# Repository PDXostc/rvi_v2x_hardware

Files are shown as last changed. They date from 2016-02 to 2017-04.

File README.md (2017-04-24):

# rvi_v2x_hardware

This repo contains the Hardware design files for the JLR OSTC V2X project. 

Firmware for an open source CAN/OBD2/2G/3G/GPS/Accelerometer with Power sequencing of RaspberryPi 2B host with RVI node installed.

Tools in use:
- Microsoft Visio - high level archetecture diagrams
- Microsoft Excel - Bill Of Materials 
- Kicad - Electrical Schematic, PCB Layout, 3D rendering, Gerber Viewer (output), Integrated BOM information. Available at http://kicad-pcb.org/
- LTspice IV - SPICE simulator, schematic capture and waveform viewer. Available at http://www.linear.com/designtools/software/
- FOXIT - PDF printer and viewer. Available at https://www.foxitsoftware.com/products/pdf-reader/

Coresponding git repositories

- Spread sheet for organizing data exported from KICad Bom wizard: https://github.com/jbanks2/KiCad-BOM-export-tool.git
- Kicad Custom Part Libraries for V2X project: https://github.com/jbanks2/Kicad_Custom_Parts.git

Primary Development by Jesse Banks - jesse@jopeldesigns.com

Jaguar Land Rover OSTC - Portland, Oregon 2015-2016

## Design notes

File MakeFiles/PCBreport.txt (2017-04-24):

Info: Reading netlist file "C:\Users\Jesse\Documents\JopelDesigns\Projects\rvi_v2x_hardware\MakeFiles\V2X.net".

Info: Using references to match components and footprints.

* Warning: component 'C51': board footprint 'CustomParts:C_0603_SM', netlist footprint 'CustomParts:C_0805_SM'

* Warning: component 'X1': board footprint 'CustomParts:AWSCR', netlist footprint 'Custom:AWSCR'

* Warning: component 'X2': board footprint 'CustomParts:AWSCR', netlist footprint 'Custom:AWSCR'

Error: No footprint defined for component 'P2'.

Error: No footprint defined for component 'W1'.

Info: Checking netlist component footprint "C1:/55AB3ADF/56065471:CustomParts:C_0603_SM".

Info: Checking netlist component footprint "C2:/55AB3ADF/56046502:CustomParts:C_0603_SM".

Info: Checking netlist component footprint "C3:/55AB3ADF/55B1F376:CustomParts:C_0603_SM".

Info: Checking netlist component footprint "C4:/55AB3ADF/5606AD61:CustomParts:C_0603_SM".

Info: Checking netlist component footprint "C5:/55AB3ADF/56048D13:CustomParts:C_0603_SM".

Info: Checking netlist component footprint "C6:/55AB3ADF/5604E07D:CustomParts:C_0603_SM".

Info: Checking netlist component footprint "C7:/55AB3ADF/5604EB81:CustomParts:C_0603_SM".

Info: Checking netlist component footprint "C8:/55AB3ADF/56049282:CustomParts:C_0805_SM".

Info: Checking netlist component footprint "C9:/55AB3ADF/5604DEF3:CustomParts:C_0603_SM".

Info: Checking netlist component footprint "C10:/55AB3ADF/5604F281:CustomParts:C_0603_SM".

Info: Checking netlist component footprint "C11:/55AB3ADF/5604F3BB:CustomParts:C_0603_SM".

Info: Checking netlist component footprint "C12:/55AB3ADF/5604ECAE:CustomParts:C_0603_SM".

Info: Checking netlist component footprint "C13:/55AB3850/55AA984D:CustomParts:C_0603_SM".

Info: Checking netlist component footprint "C14:/55AB3850/567B0C07:Capacitors_SMD:c_elec_6.3x5.8".

Info: Checking netlist component footprint "C15:/55AB3850/55FBBA04:CustomParts:C_0603_SM".

Info: Checking netlist component footprint "C16:/55AB3850/567B0BF4:CustomParts:C_0805_SM".

Info: Checking netlist component footprint "C17:/55AB3850/56290CF9:CustomParts:C_0603_SM".

Changing component "C17:/55AB3850/56290CF9" pin "1" net name from "GND" to "BUTTON".

Changing component "C17:/55AB3850/56290CF9" pin "2" net name from "BUTTON" to "GND".

Info: Checking netlist component footprint "C18:/55AB3850/567B0C17:CustomParts:C_0603_SM".

Info: Checking netlist component footprint "C19:/55AB3850/55AAA21C:Capacitors_SMD:c_elec_6.3x5.8".

Info: Checking netlist component footprint "C20:/55AB3850/560779B3:CustomParts:C_1206_SM".

Info: Checking netlist component footprint "C21:/55AB3850/567B0C2F:Capacitors_SMD:c_elec_6.3x5.8".

Info: Checking netlist component footprint "C22:/55AB3850/567B0BDB:CustomParts:C_0603_SM".

Info: Checking netlist component footprint "C23:/55AB3850/567B0C27:CustomParts:C_0805_SM".

Info: Checking netlist component footprint "C24:/55AB3850/55FBBA48:CustomParts:C_1206_SM".

Info: Checking netlist component footprint "C25:/55AB3850/567B8999:CustomParts:C_0603_SM".

Info: Checking netlist component footprint "C26:/55AB3850/567B0C3F:CustomParts:C_0603_SM".

Info: Checking netlist component footprint "C27:/55AB3850/567B8991:CustomParts:C_0805_SM".

Info: Checking netlist component footprint "C28:/55AB3850/567B0C95:CustomParts:C_1206_SM".

Info: Checking netlist component footprint "C29:/55AB3850/567B15E2:CustomParts:C_0603_SM".

Info: Checking netlist component footprint "C30:/55AB3850/567B0C9D:CustomParts:C_1206_SM".

Info: Checking netlist component footprint "C31:/55AB3850/567B0CA5:CustomParts:C_1206_SM".

Info: Checking netlist component footprint "C32:/55AB3850/567B237E:CustomParts:C_0603_SM".

Info: Checking netlist component footprint "C33:/55F8B2F2/56053914:CustomParts:C_0603_SM".

Info: Checking netlist component footprint "C34:/55F8B2F2/55F8B394:CustomParts:C_0603_SM".

Info: Checking netlist component footprint "C35:/55F8B2F2/56053A8A:CustomParts:C_0603_SM".

Info: Checking netlist component footprint "C36:/55F8B2F2/567BDBCA:CustomParts:C_0603_SM".

Info: Checking netlist component footprint "C37:/55F8B2F2/567BDBA4:CustomParts:C_0805_SM".

Info: Checking netlist component footprint "C38:/55F8B2F2/56053852:CustomParts:C_0603_SM".

Info: Checking netlist component footprint "C39:/55AB3850/569FD08D:CustomParts:C_0603_SM".

Info: Checking netlist component footprint "C40:/55AB3850/569FD0B0:CustomParts:C_0603_SM".

Info: Checking netlist component footprint "C41:/55F91B74/56052557:CustomParts:C_0603_SM".

Info: Checking netlist component footprint "C42:/55F91B74/56052E12:CustomParts:C_0603_SM".

Info: Checking netlist component footprint "C43:/55F91B74/56052E7D:CustomParts:C_0603_SM".

Info: Checking netlist component footprint "C44:/55F91B74/56052EE9:CustomParts:C_0603_SM".

Info: Checking netlist component footprint "C45:/55F91B74/56052F58:CustomParts:C_0603_SM".

Info: Checking netlist component footprint "C46:/55F91B74/56059C07:CustomParts:C_0603_SM".

Info: Checking netlist component footprint "C47:/562004BB/55A9296E:Capacitors_ThroughHole:C_Radial_D12.5_L25_P5".

Info: Checking netlist component footprint "C48:/562004BB/55A9A6E2:CustomParts:C_0603_SM".

Info: Checking netlist component footprint "C49:/562004BB/5603FFF9:CustomParts:C_0603_SM".

Info: Checking netlist component footprint "C50:/562004BB/5603E72B:CustomParts:C_0603_SM".

Info: Checking netlist component footprint "C51:/562004BB/560FE5DA:CustomParts:C_0805_SM".

Info: Checking netlist component footprint "C52:/55F91B74/56A157E6:CustomParts:C_0603_SM".

Info: Checking netlist component footprint "C53:/55F91B74/56DA13C3:CustomParts:C_0603_SM".

Info: Checking netlist component footprint "C54:/55F91B74/56DA1977:CustomParts:C_0603_SM".

Info: Checking netlist component footprint "C55:/55AB3850/58E1BBA0:CustomParts:C_1206_SM".

Adding new component "C55:/55AB3850/58E1BBA0" footprint "CustomParts:C_1206_SM".

Info: Checking netlist component footprint "D1:/55AB3ADF/5605B7C0:CustomParts:Diode_0805_12_SM".

Info: Checking netlist component footprint "D2:/55AB3ADF/55B40CD4:CustomParts:Diode_0805_12_SM".

Info: Checking netlist component footprint "D3:/55AB3ADF/56046C18:CustomParts:Diode_0805_12_SM".

Info: Checking netlist component footprint "D4:/55AB3ADF/5605B14B:CustomParts:Diode_0805_12_SM".

Info: Checking netlist component footprint "D5:/55AB3ADF/5605AAE2:CustomParts:Diode_0805_12_SM".

Info: Checking netlist component footprint "D6:/55AB3850/55AAA079:Diodes_SMD:SMB_Standard".

Info: Checking netlist component footprint "D7:/55AB3850/55AAA128:Diodes_SMD:SMA_Standard".

Info: Checking netlist component footprint "D8:/55AB3850/5607A783:CustomParts:SOD-123".

Info: Checking netlist component footprint "D9:/55AB3850/56454B6A:CustomParts:Diode_0805_12_SM".

Info: Checking netlist component footprint "D10:/55AB3850/567B0C5F:CustomParts:SOD-123".

Info: Checking netlist component footprint "D11:/55F91B74/560D95B2:CustomParts:0805_LED".

Info: Checking netlist component footprint "D12:/55F91B74/55FD725A:CustomParts:0805_LED".

Info: Checking netlist component footprint "D13:/55F91B74/55FD764E:CustomParts:0805_LED".

Info: Checking netlist component footprint "F1:/55AB3850/55A6CDC7:Resistors_SMD:R_1812".

Info: Checking netlist component footprint "F2:/55AB3850/55C7D59B:Resistors_SMD:R_1812".

Info: Checking netlist component footprint "FB1:/55AB3ADF/5604928A:CustomParts:R_0603_sm".

Info: Checking netlist component footprint "FB2:/55AB3850/567B0BD3:CustomParts:R_0603_sm".

Info: Checking netlist component footprint "FB3:/55F8B2F2/567BDBAC:CustomParts:R_0603_sm".

Info: Checking netlist component footprint "FB4:/55F91B74/56059F9F:CustomParts:R_0603_sm".

Info: Checking netlist component footprint "J1:/55AB3ADF/55B3C04C:Custom:DB-9_SMT".

Info: Checking netlist component footprint "L1:/55AB3850/5607B402:CustomParts:L_4.5x4.5".

Info: Checking netlist component footprint "L2:/55AB3850/567B0CB5:CustomParts:L_4.5x4.5".

Info: Checking netlist component footprint "L3:/562004BB/5603E335:CustomParts:L_0603_SM".

Info: Checking netlist component footprint "L4:/562004BB/55A9A7AD:CustomParts:L_0603_SM".

Info: Checking netlist component footprint "P1:/55AB3ADF/55AA08F9:CustomParts:R_0603_sm".

Info: Checking netlist component footprint "P2:/55AB3ADF/55B92A71:".

Error: Cannot add new component "P2:/55AB3ADF/55B92A71" due to missing footprint "".

Info: Checking netlist component footprint "P3:/55AB3850/561FEF14:CustomParts:USB-A-SMT".

Info: Checking netlist component footprint "P4:/55AB3850/55C35935:Mounting_Holes:MountingHole_3mm".

Info: Checking netlist component footprint "P5:/55AB3850/55C3593C:Mounting_Holes:MountingHole_3mm".

Info: Checking netlist component footprint "P6:/55AB3850/55C35943:Mounting_Holes:MountingHole_3mm".

Info: Checking netlist component footprint "P7:/55AB3850/55C3594A:Mounting_Holes:MountingHole_3mm".

Info: Checking netlist component footprint "P8:/55AB3850/55C35919:Fiducials:Fiducial_1mm_Dia_2.54mm_Outer_CopperTop".

Info: Checking netlist component footprint "P9:/55AB3850/55C35920:Fiducials:Fiducial_1mm_Dia_2.54mm_Outer_CopperTop".

Info: Checking netlist component footprint "P10:/55AB3850/55C35927:Fiducials:Fiducial_1mm_Dia_2.54mm_Outer_CopperTop".

Info: Checking netlist component footprint "P11:/55AB3850/55C3592E:Fiducials:Fiducial_1mm_Dia_2.54mm_Outer_CopperTop".

Info: Checking netlist component footprint "P12:/55AB3850/562955D0:Fiducials:Fiducial_1mm_Dia_2.54mm_Outer_CopperBottom".

Info: Checking netlist component footprint "P13:/55AB3850/562955D6:Fiducials:Fiducial_1mm_Dia_2.54mm_Outer_CopperBottom".

Info: Checking netlist component footprint "P14:/55AB3850/562955DC:Fiducials:Fiducial_1mm_Dia_2.54mm_Outer_CopperBottom".

Info: Checking netlist component footprint "P15:/55AB3850/562955E2:Fiducials:Fiducial_1mm_Dia_2.54mm_Outer_CopperBottom".

Info: Checking netlist component footprint "P16:/55F8B2F2/567BADA8:CustomParts:USB_Micro-B-DX4R005JJ2R1800".

Info: Checking netlist component footprint "P22:/562004BB/5603F238:CustomParts:SMA-RA_142-0701-801".

Info: Checking netlist component footprint "P23:/562004BB/55A9FAEF:CustomParts:SMA-RA_142-0701-801".

Info: Checking netlist component footprint "P24:/562004BB/55A754E2:CustomParts:47553-1001".

Info: Checking netlist component footprint "PDI1:/55F91B74/55F86EF7:Pin_Headers:Pin_Header_Straight_2x03".

Info: Checking netlist component footprint "Q1:/55AB3ADF/5605E65B:CustomParts:SOT_23_123".

Info: Checking netlist component footprint "Q2:/55AB3ADF/5605E101:CustomParts:SOT_23_123".

Info: Checking netlist component footprint "Q3:/55AB3ADF/5605DFA8:CustomParts:SOT_23_123".

Info: Checking netlist component footprint "Q4:/55AB3ADF/560643DB:CustomParts:SOT_23_123".

Info: Checking netlist component footprint "Q5:/55AB3ADF/55B35B80:CustomParts:SOT_23_123".

Info: Checking netlist component footprint "Q6:/55AB3ADF/55B35FD6:CustomParts:SOT_23_123".

Info: Checking netlist component footprint "Q7:/55AB3ADF/560521FD:CustomParts:SOT_23_123".

Info: Checking netlist component footprint "Q8:/55AB3ADF/560520AD:CustomParts:SOT_23_123".

Info: Checking netlist component footprint "Q9:/55AB3ADF/56052C71:CustomParts:SOT_23_123".

Info: Checking netlist component footprint "Q10:/55AB3ADF/55B7C06D:CustomParts:SOT_23_123".

Info: Checking netlist component footprint "Q11:/55AB3850/5607ABF7:CustomParts:SOIC-8_MOS".

Info: Checking netlist component footprint "Q12:/55AB3850/567B0CAD:CustomParts:SOIC-8_MOS".

Info: Checking netlist component footprint "Q15:/55F91B74/55FE0BA7:CustomParts:SOT_23_123".

Info: Checking netlist component footprint "R1:/55AB3ADF/55B20162:CustomParts:R_1210_SM".

Info: Checking netlist component footprint "R2:/55AB3ADF/56062E2E:CustomParts:R_1210_SM".

Info: Checking netlist component footprint "R3:/55AB3ADF/56068A93:CustomParts:R_0603_sm".

Info: Checking netlist component footprint "R4:/55AB3ADF/55B2AB74:CustomParts:R_0603_sm".

Info: Checking netlist component footprint "R5:/55AB3ADF/560629BB:CustomParts:R_0603_sm".

Info: Checking netlist component footprint "R6:/55AB3ADF/56062B17:CustomParts:R_0603_sm".

Info: Checking netlist component footprint "R7:/55AB3ADF/5605C4B6:CustomParts:R_0603_sm".

Info: Checking netlist component footprint "R8:/55AB3ADF/5605C5FE:CustomParts:R_0603_sm".

Info: Checking netlist component footprint "R9:/55AB3ADF/5605C791:CustomParts:R_0603_sm".

Info: Checking netlist component footprint "R10:/55AB3ADF/56060ABE:CustomParts:R_0603_sm".

Info: Checking netlist component footprint "R11:/55AB3ADF/56061D1B:CustomParts:R_0603_sm".

Info: Checking netlist component footprint "R12:/55AB3ADF/5605C36B:CustomParts:R_0603_sm".

Info: Checking netlist component footprint "R13:/55AB3ADF/5605DA36:CustomParts:R_0603_sm".

Info: Checking netlist component footprint "R14:/55AB3ADF/5605C1F3:CustomParts:R_0603_sm".

Info: Checking netlist component footprint "R15:/55AB3ADF/5605DB8E:CustomParts:R_0603_sm".

Info: Checking netlist component footprint "R16:/55AB3ADF/5605D779:CustomParts:R_0603_sm".

Info: Checking netlist component footprint "R17:/55AB3ADF/5605D8F7:CustomParts:R_0603_sm".

Info: Checking netlist component footprint "R18:/55AB3ADF/5605BA35:CustomParts:R_0603_sm".

Info: Checking netlist component footprint "R19:/55AB3ADF/55B355D8:CustomParts:R_0603_sm".

Info: Checking netlist component footprint "R20:/55AB3ADF/55B35518:CustomParts:R_0603_sm".

Info: Checking netlist component footprint "R21:/55AB3ADF/5605BC94:CustomParts:R_0603_sm".

Info: Checking netlist component footprint "R22:/55AB3ADF/55B1F414:CustomParts:R_0603_sm".

Info: Checking netlist component footprint "R23:/55AB3ADF/5605BE37:CustomParts:R_0603_sm".

Info: Checking netlist component footprint "R24:/55AB3ADF/55BD0AC0:CustomParts:R_0603_sm".

Info: Checking netlist component footprint "R25:/55AB3ADF/55BD137A:CustomParts:R_0603_sm".

Info: Checking netlist component footprint "R26:/55AB3ADF/5606AA56:CustomParts:R_0603_sm".

Info: Checking netlist component footprint "R27:/55AB3ADF/55B34CA2:CustomParts:R_0603_sm".

Info: Checking netlist component footprint "R28:/55AB3ADF/5605B2E0:CustomParts:R_0603_sm".

Info: Checking netlist component footprint "R29:/55AB3ADF/5606B363:CustomParts:R_0603_sm".

Info: Checking netlist component footprint "R30:/55AB3ADF/560537AD:CustomParts:R_0603_sm".

Info: Checking netlist component footprint "R31:/55AB3ADF/5605393B:CustomParts:R_0603_sm".

Info: Checking netlist component footprint "R32:/55AB3ADF/55AA1169:CustomParts:R_0603_sm".

Info: Checking netlist component footprint "R33:/55AB3ADF/5655F6EA:CustomParts:R_0603_sm".

Info: Checking netlist component footprint "R34:/55AB3ADF/56058495:CustomParts:R_0603_sm".

Info: Checking netlist component footprint "R35:/55AB3ADF/5605879F:CustomParts:R_0603_sm".

Info: Checking netlist component footprint "R36:/55AB3ADF/56059C7F:CustomParts:R_0603_sm".

Info: Checking netlist component footprint "R37:/55AB3850/56081053:CustomParts:R_0603_sm".

Info: Checking netlist component footprint "R38:/55AB3850/5608243D:CustomParts:R_0603_sm".

Info: Checking netlist component footprint "R39:/55AB3850/5608085B:CustomParts:R_0603_sm".

Info: Checking netlist component footprint "R40:/55AB3850/5608BED0:CustomParts:R_0603_sm".

Info: Checking netlist component footprint "R41:/55AB3850/56081C97:CustomParts:R_0603_sm".

Info: Checking netlist component footprint "R42:/55AB3850/560811F0:CustomParts:R_0603_sm".

Info: Checking netlist component footprint "R43:/55AB3850/56081A63:CustomParts:R_0603_sm".

Info: Checking netlist component footprint "R44:/55AB3850/56081EB1:CustomParts:R_0603_sm".

Info: Checking netlist component footprint "R45:/55AB3850/567B0CC5:CustomParts:R_0603_sm".

Info: Checking netlist component footprint "R46:/55AB3850/5644A6DA:CustomParts:R_0603_sm".

Info: Checking netlist component footprint "R47:/55AB3850/567B0CCD:CustomParts:R_0603_sm".

Info: Checking netlist component footprint "R51:/55AB3850/5627A597:CustomParts:R_0603_sm".

Info: Checking netlist component footprint "R52:/55AB3850/5627A58F:CustomParts:R_0603_sm".

Info: Checking netlist component footprint "R53:/55F8B2F2/5627871B:CustomParts:R_0603_sm".

Info: Checking netlist component footprint "R54:/55F8B2F2/56278723:CustomParts:R_0603_sm".

Info: Checking netlist component footprint "R55:/55F8B2F2/55F89B1E:CustomParts:R_0603_sm".

Info: Checking netlist component footprint "R56:/55F8B2F2/567BBCB0:CustomParts:R_0603_sm".

Info: Checking netlist component footprint "R57:/55F8B2F2/5627F762:CustomParts:R_0603_sm".

Info: Checking netlist component footprint "R58:/55F8B2F2/5627F427:CustomParts:R_0603_sm".

Info: Checking netlist component footprint "R59:/55F8B2F2/567BBCEF:CustomParts:R_0603_sm".

Info: Checking netlist component footprint "R61:/55F91B74/560D95D8:CustomParts:R_0603_sm".

Info: Checking netlist component footprint "R63:/55F91B74/5605C9A1:CustomParts:R_0603_sm".

Info: Checking netlist component footprint "R66:/55F91B74/562AAD52:CustomParts:R_0603_sm".

Info: Checking netlist component footprint "R67:/55F91B74/5605AFDD:CustomParts:R_0603_sm".

Info: Checking netlist component footprint "R69:/562004BB/5603C783:CustomParts:R_0603_sm".

Info: Checking netlist component footprint "R70:/562004BB/55A77FC7:CustomParts:R_0603_sm".

Info: Checking netlist component footprint "R71:/562004BB/5603C7FB:CustomParts:R_0603_sm".

Info: Checking netlist component footprint "SW1:/55AB3ADF/55F7E47B:CustomParts:SW_SPST_FSMSM_SM".

Info: Checking netlist component footprint "SW2:/55AB3850/5600CE81:CustomParts:PTS645VK58-2-LFS".

Info: Checking netlist component footprint "U1:/55AB3ADF/55B2A9F7:Housings_SOIC:SOIC-14_3.9x8.7mm_Pitch1.27mm".

Info: Checking netlist component footprint "U2:/55AB3ADF/55C1089B:TO_SOT_Packages_SMD:SOT-23-6".

Info: Checking netlist component footprint "U3:/55AB3ADF/5604541F:TO_SOT_Packages_SMD:SOT-23-6".

Info: Checking netlist component footprint "U4:/55AB3ADF/55B33F41:TO_SOT_Packages_SMD:SOT-223".

Info: Checking netlist component footprint "U5:/55AB3ADF/55B1E71A:Housings_SOIC:SOIC-8_3.9x4.9mm_Pitch1.27mm".

Info: Checking netlist component footprint "U6:/55AB3ADF/55A9EA92:Housings_SOIC:SOIC-28_7.5x17.9mm_Pitch1.27mm".

Info: Checking netlist component footprint "U7:/55AB3850/5643FA88:TO_SOT_Packages_SMD:SOT-23-6".

Info: Checking netlist component footprint "U8:/55AB3850/5607E4F1:TO_SOT_Packages_SMD:SOT-23-5".

Info: Checking netlist component footprint "U9:/55AB3850/567B0CBD:TO_SOT_Packages_SMD:SOT-23-5".

Info: Checking netlist component footprint "U10:/55AB3850/56A695E2:TO_SOT_Packages_SMD:SOT-23-6".

Info: Checking netlist component footprint "U11:/55AB3850/567B8989:TO_SOT_Packages_SMD:SOT-23-5".

Info: Checking netlist component footprint "U12:/55AB3850/567B15D2:TO_SOT_Packages_SMD:SOT-23-5".

Info: Checking netlist component footprint "U13:/55AB3850/569FD086:TO_SOT_Packages_SMD:SOT-23-5".

Info: Checking netlist component footprint "U16:/55F8B2F2/55F88FA9:Housings_DFN_QFN:QFN-24-1EP_4x4mm_Pitch0.5mm".

Info: Checking netlist component footprint "U17:/55F8B2F2/567BDB8D:CustomParts:LGA-14_5x3mm".

Info: Checking netlist component footprint "U18:/55F91B74/55FA3B36:Housings_SOIC:SOIC-16_3.9x9.9mm_Pitch1.27mm".

Info: Checking netlist component footprint "U20:/55F91B74/55F86EE3:Housings_QFP:TQFP-44_10x10mm_Pitch0.8mm".

Info: Checking netlist component footprint "U22:/562004BB/55A744B0:CustomParts:SIM5320".

Info: Checking netlist component footprint "U23:/562004BB/56099894:TO_SOT_Packages_SMD:SOT-23-6".

Info: Checking netlist component footprint "W1:/562004BB/55B87E9D:".

Error: Cannot add new component "W1:/562004BB/55B87E9D" due to missing footprint "".

Info: Checking netlist component footprint "X1:/55AB3ADF/55B75E65:Custom:AWSCR".

Info: Checking netlist component footprint "X2:/55F8B2F2/56092E15:Custom:AWSCR".

Info: Checking netlist component footprint "X3:/55F91B74/56DA0FEF:Custom Parts:C_1206_SM".

Error: Component 'P8' pad '1' not found in footprint 'Fiducials:Fiducial_1mm_Dia_2.54mm_Outer_CopperTop'

Error: Component 'P9' pad '1' not found in footprint 'Fiducials:Fiducial_1mm_Dia_2.54mm_Outer_CopperTop'

Error: Component 'P10' pad '1' not found in footprint 'Fiducials:Fiducial_1mm_Dia_2.54mm_Outer_CopperTop'

Error: Component 'P11' pad '1' not found in footprint 'Fiducials:Fiducial_1mm_Dia_2.54mm_Outer_CopperTop'

Error: Component 'P12' pad '1' not found in footprint 'Fiducials:Fiducial_1mm_Dia_2.54mm_Outer_CopperBottom'

Error: Component 'P13' pad '1' not found in footprint 'Fiducials:Fiducial_1mm_Dia_2.54mm_Outer_CopperBottom'

Error: Component 'P14' pad '1' not found in footprint 'Fiducials:Fiducial_1mm_Dia_2.54mm_Outer_CopperBottom'

Error: Component 'P15' pad '1' not found in footprint 'Fiducials:Fiducial_1mm_Dia_2.54mm_Outer_CopperBottom'

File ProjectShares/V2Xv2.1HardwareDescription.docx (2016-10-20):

# V2X v2 Hardware Description

Author Jesse Banks

## Architecture

The design of the V2X board has an Atmel microcontroller at its heart. The atmel has 4 primary jobs:

1. control system/sub-system power states and sequencing,
2. creates a control/reporting interface (AT style) for each system,
3. serial adapter/pass through for the ELM327/STN1110 chip,
4. samples and generates a serial stream from accelerometer data.

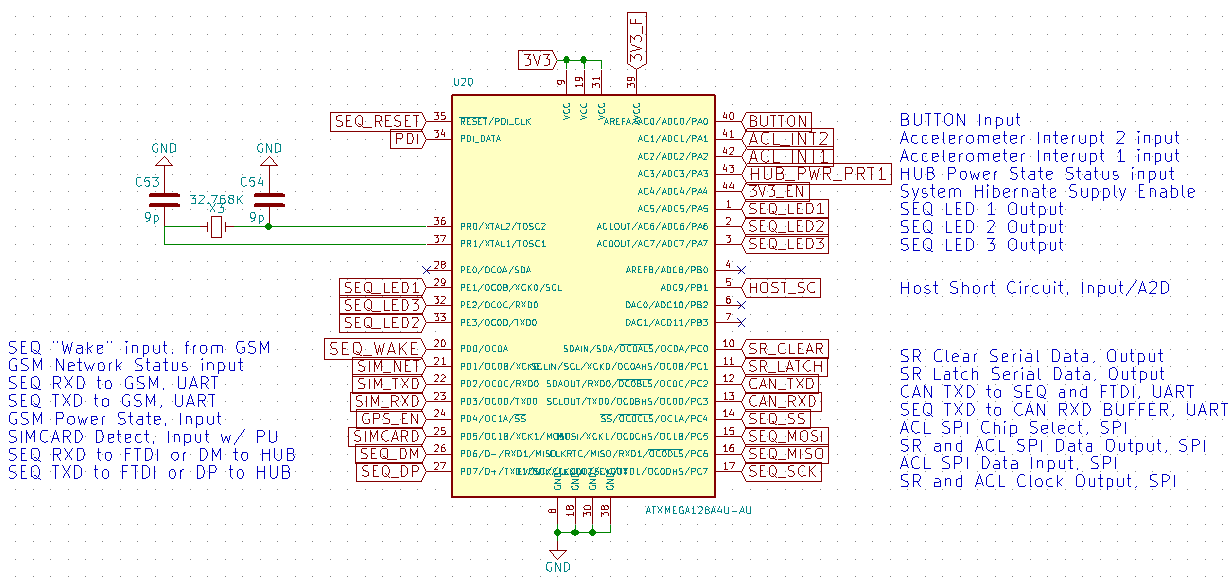
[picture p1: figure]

## Button

When the v2x board first receives power it should remain in an off state. the board has a singular button with dual purposes, starting power and soft button. pressing the button will temporarily enable the 4v1 power supply, passing power through U12 and providing power to the atmel ATmega chip.

The first action of the Atmel needs to be resetting shift registers to the default 0 state, then sending the 4V1_EN or 3V3_EN signal to keep the 3V3 Volt Power System alive. Once the button is released, the 3.3V power supply will shut off if the 4V1_EN or 3V3_EN is not pulled high by the Shift registers.

After starting power, the button it will transition to a soft button function. The BUTTON signal is routed to the ATmega Port A0. It produces a positive logic signal (pin goes high on press). The command interface will report press and release events through the CMD usb port, and will have the following forms:

Press event: Sent to CMD interface: ”BTN:>PRESS\n”

Release event: Sent to CMD interface: ”BTN:>RELEASE:(seconds pressed)\n”

Here is an expeted terminal report:

BTN>:PRESS

BTN>:RELEASE:1

BTN>:PRESS

BTN>:RELEASE:4

## LED

SEQ_LED1, 2, 3 are all negative logic signals, a logic low causes the light to turn on. They can be pulsed at 1-10’s of Khz to create fading using OC0B, OC0C and OC0D (PE1-3).

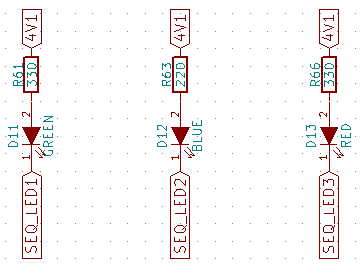
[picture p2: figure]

## Shift registers

The method for controlling power switches and reset signals throughout the board is handled by a 74HC595 serial shift register. the shift register uses the ATmega SPI peripheral bus signals SCK and MOSI, along with dedicated clear and latch signals. Output Enable is signal “G” it is tied to ground so that the outputs are always on, and never high impedance.

The shift register data sheet is here (http://www.mouser.com/ds/2/302/74HC_HCT595_Q100-269352.pdf)

The operational state of SR_CLEAR is ‘1’ (not clear). The shift register reset procedure involves setting SR_CLEAR to ‘0’ (this clears all the shift registers) then cycling SR_LATCH 0->1->0 (moves the clear SR value to the output buffers) and setting SR_CLEAR to ‘1’ again. this operation loads all ‘0’s to the outputs and puts the control signals back in their default states.

SR_CLEAR

SR_LATCH

“1”

“0”

3V3_EN: (not from SR) Low power supply for idle and sleep modes.

4V1_EN: main power supply, needed for GSM and GPS.

5V0_EN Starts switching supply for 5V0 power rail. CAN and HOST

5V0_B_EN: load switch powering HOST

/CAN_SLEEP: suspend signal to CAN device (active low)

/CAN_RESET: reset signal for CAN device (active low)

SIM_PWR_ON: wake-up/shut-down pulse signal

/SIM_RESET: causes the SIM GSM/GPS module to reset

SIM_WAKE: cycles SIM module between sleep and wake states (not implemented yet)

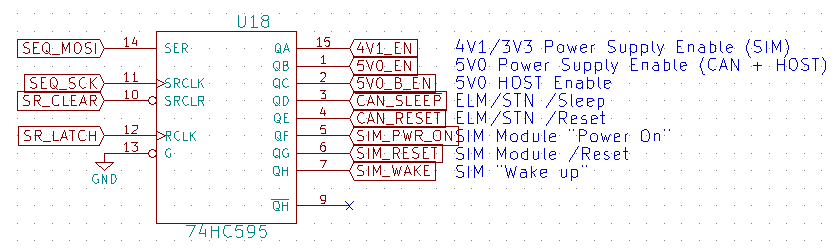
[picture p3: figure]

### 4V1_EN, Main Power

Power switches allow for controlling power to the ATmega, accelerometer, CAN bus controller, GSM/GPS modem, USB hub and FTDI along with the HOST computer itself.

The 3V3 power rail is critical to the ATmega for operation. The 3V3 power can come from 2 sources, but should only be using one at a time (minimize overlap). Identical LDO linear regulators sourcing from 4v1 and filtered 12V are available.

Since linear regulation is wasteful, 4V1 should be used whenever possible. For this reason the enable pin of U12 is tied to 4V1 and will automatically power the 3V3 rail if the 4V1 rail is powered. In this case U13 should be disabled by holding 3V3_EN low. If 4V1 is being powered off for sleep mode then 3V3_EN (port A0) should be set high immediately prior the change, to keep the ATmega alive.

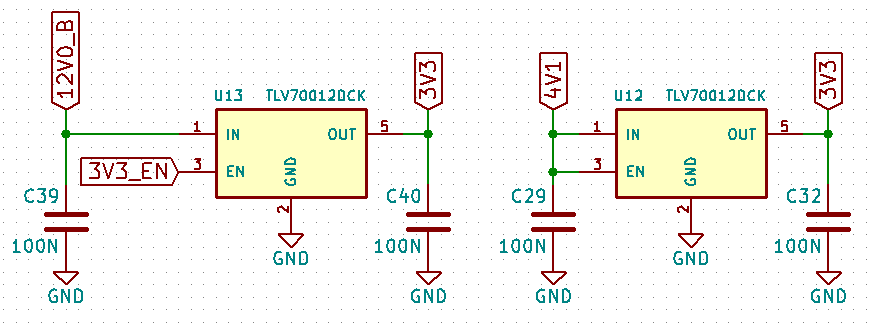
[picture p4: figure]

### 5V0_EN and 5V0_B_EN, CAN and HOST Power

The 5V0_EN signal is set high to start the 5volt power supply, U8. After a short delay (100ms guess) for supply stabilization, the 5V0_B_EN signal is set high to provide the host with power (5V0_B) through power switch U10.

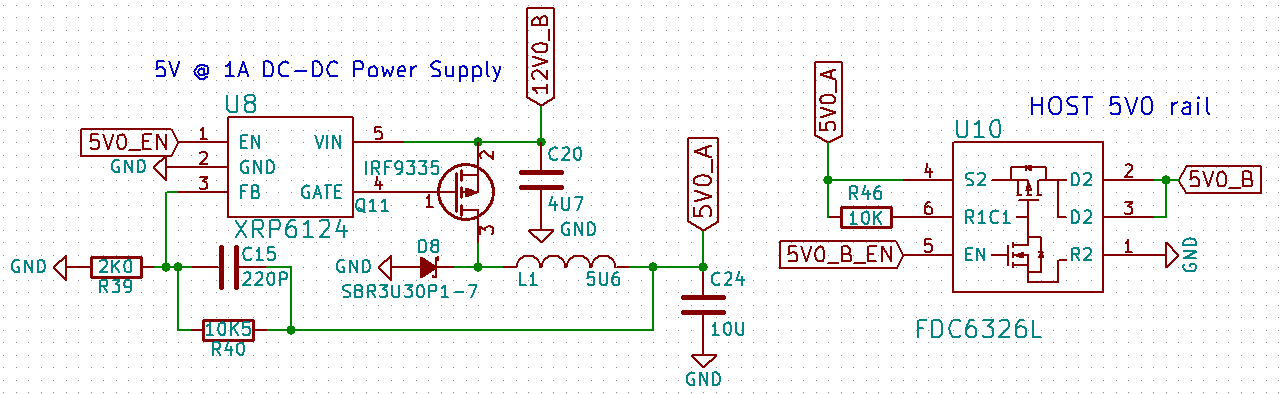
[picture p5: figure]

The HOST would typically be a Raspberry Pi 3, but it could also be a beaglebone, minnowmax, Rpi 1/2, etc. The host receives power from V2X port P3, the USB-A Female port.

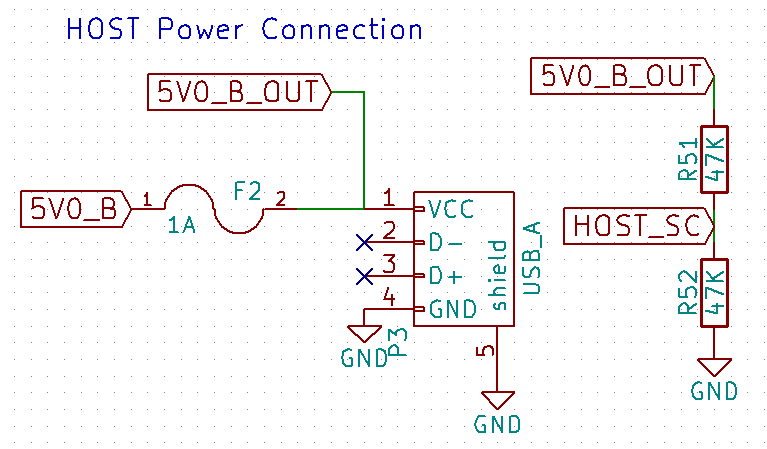
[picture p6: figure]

While 5V0_B_EN is active, HOST_SC could be monitored to determine if there is a short circuit or overload, setting the poly fuse open. if HOST_SC is read as a logic ‘1’ the host is receiving power. A logic ‘0’ indicates the fuse is protecting the power supply. Alternately ADC9 can take an analog sample possibly indicating power usage without overload, nominal values are unknown.

Once the HOST is started the ATmega receives AT-like commands that allows the HOST to modify the power modes and access other features.

### CAN_SLEEP

External sleep control input. When enabled in firmware, puts the device into low - power sleep mode. Polarity of this pin can be configured in firmware; default configuration is active low. Internal pull-up to VDD is enabled by default, but can be disabled in firmware. When STN11xx senses a logic low on the SLEEP pin, it immediately aborts any OBD reception in progress, or monitoring command that is active at the time, and prints the command prompt. It then monitors the SLEEP input and enters the Power Save mode if the minimum low time (specified by the STSLXST command) is satisfied.

### CAN_RESET

Device reset input. A logic low pulse (min 2μs) on this pin will reset the device. Apply a continuous logic low to hold the device in reset.

### SIM_PWR_ON

The SIM5320 module expects a negative pulse to start the module. Here is a quick clip of the SIM module data sheet:

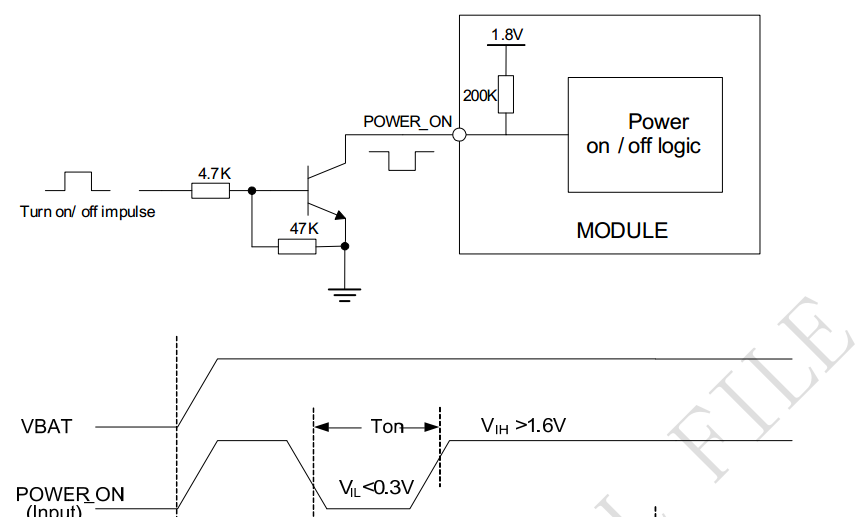
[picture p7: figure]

Q15 transfers a positive pulse from the shift register into the negative signal the SIM is expecting. Also, the Shift register default 0 state should not trigger the SIM module to start falsely. This circuit changes SIM_PWR_ON into SIM_PWR_ON

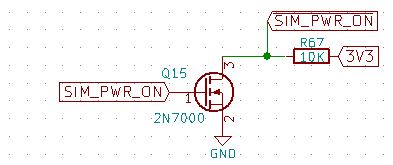
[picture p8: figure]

### SIM_RESET

Should be high to operate the SIM5320 module. Only necessary to use as reset command if SIM stops responding to AT commands.

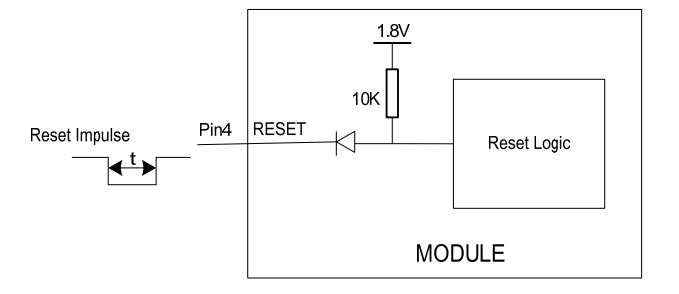
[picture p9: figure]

### SIM_WAKE

The signal wakes the GSM/GPS module from sleep. Not currently implemented, likely requires configuration of SIM module to use.

## Data Paths

HOST Control of the V2X is handled completely over USB. As USB enters the board it lands on a 2 port hub. the hub sends the USB signals to the SIM5320 module and the ATmega.

The SIM produces a 5x USB endpoint interface. they provide the NMEA GPS stream, virtual modem, SMS and GSM control.

The ATmega firmware performs 3 roles (with 3 corresponding USB endpoints): Accelerometer stream, CAN interface serial bypass and system level power sequencing control.

Internal

Internal

Internal

Serial

USB

USB

HOST
USB PORT

2x HUB

ATMEL

USB

CAN

ACL

SIM5320

CMD

Internal

SPI

Serial

GPS

GSM 3G

SMS

## USB Hub

The design uses a USB2422, 2-port automatic hub. Datasheet (http://www.mouser.com/ds/2/268/2422-319423.pdf)

HUB_RESET is automatically pulled low by the chip. It is released by an upstream USB Vdd supply (HOST) connection.

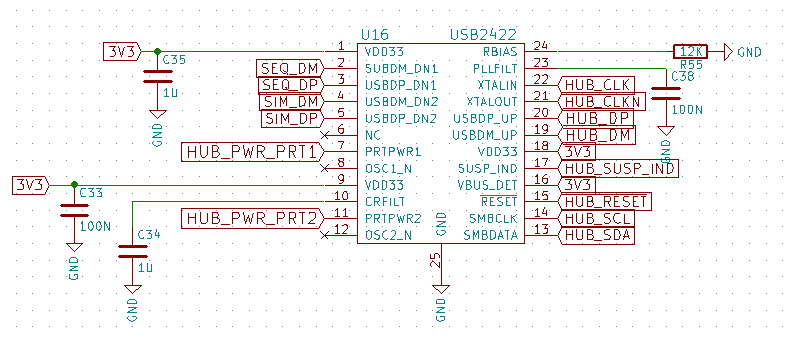
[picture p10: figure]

With the default board configuration the hub should activate and operate automatically as a bus powered 2-port hub. Logic states on several pins are sampled when the 2422 leaves reset (signal goes high) to determine the mode of operation.

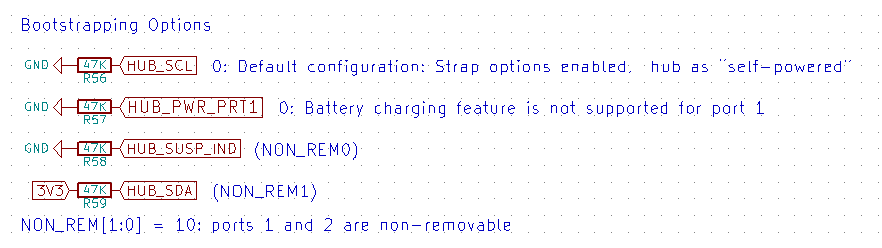
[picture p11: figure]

Non default configurations allow for complete setup and configuration of the hub through SMBUS (I2C) communications. See the datasheet for all the confusion you can handle.

## Serial Data

The ATmega is serially connected to the SIM5320 module and the STN1110. This system has multiple options for configuration.

The driver in the ATmega understands when the USB passthrough channel is open to the HOST. While the HOST is offline (and special modes) the Atmel can directly access the CAN device to search for ignition evidence.

## SIM5320

The GPS System is backed up by a super capacitor for rapid satellite acquisition. First acquisition can take 30+ seconds or more, subsequent acquisitions should be <1 second. The super capacitor should keep the GPS clock running for 36+ hours based on limited info.

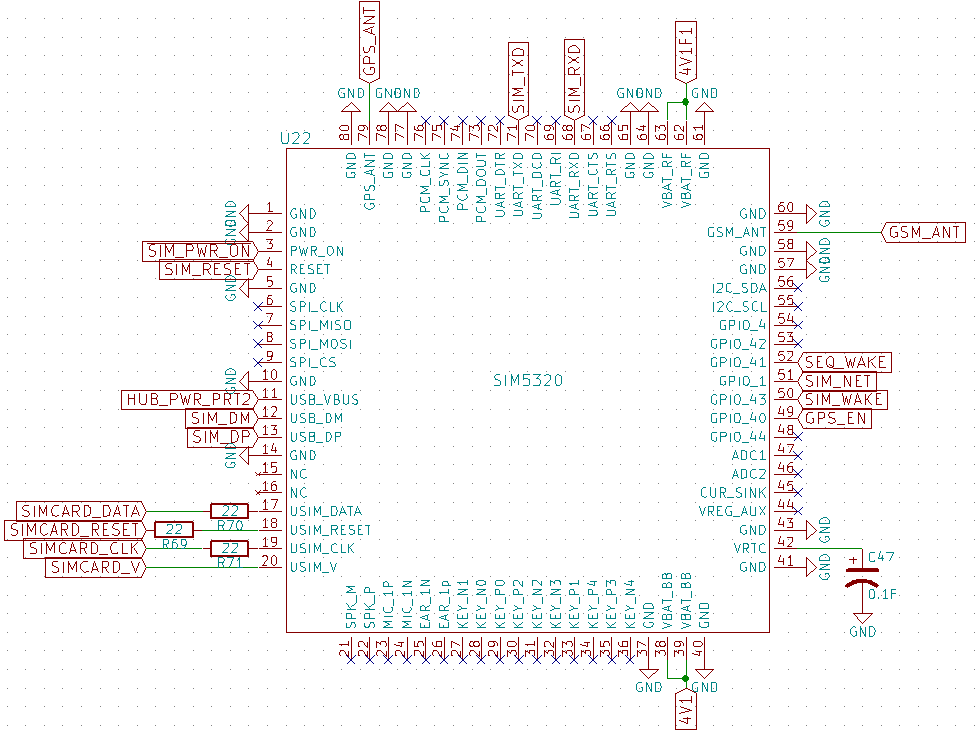
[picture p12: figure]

The primary means of controlling the SIM5320 is by USB connection (SIM_DM, SIM_DP). All functions are mirrored onto a single serial channel with functional multiplexing. The serial method is far more complicated, but gives access to the ATmega while the host is off. Excerpt from the data sheet.

USB mounting is automatically triggered by HUB_PWR_PRT2 signal, generated when the hub successfully mounts to the HOST. USB_VBUS is low otherwise and the USB port is deactivated.

The SIM5320 gets GSM subscription information from a sim card just like any other cell phone. Sim card Card Logic voltage detection and operation is handled automatically.

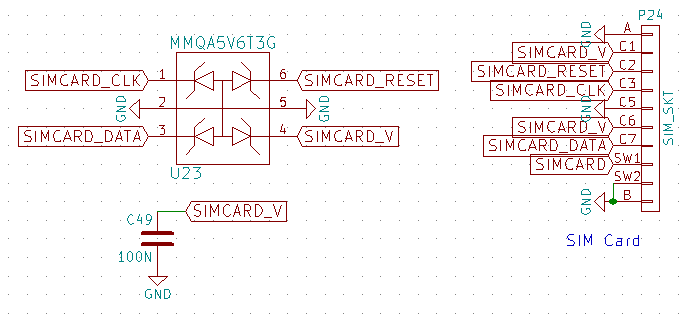
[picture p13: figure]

The sim card socket has a switch (SW1<->SW2) that will close (short) when the card is inserted. PD5 must be configured with a pullup resistor to detect the closed switch to ground. Therefore; SIMCARD, signalling PD5, uses negative logic. When the pin is high there is no sim card in the socket. For highest power efficiency the port-pullup should only be enabled several microseconds before a reading is taken, and disabled immediately afterward, else idle currents will continue to flow.

The SIM connections at the ATmega:

The GPIO connections at the SIM module are:

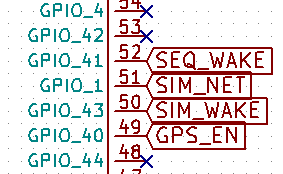
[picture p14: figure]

GPIO functions from the data sheet

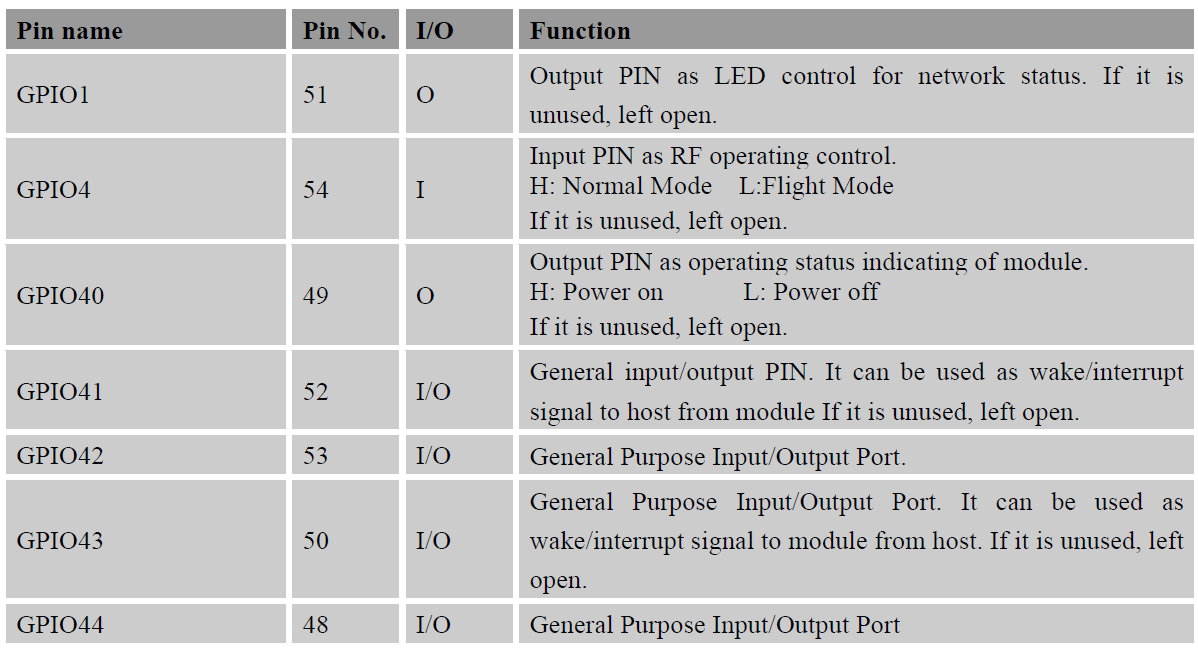
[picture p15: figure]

### GPS_EN

The SIM5320 module is default configured to indicate its power state from GPIO40 (as seen above). The GPS_EN signal sent by this pin serves two purposes; it allows the ATmega to directly sample the power state of the SIM, and it enables the active antenna power supply, necessary for the GPS antenna to operate.

## Accelerometer

Accelerometer measurements are taken by an ADXL345 produced by analog devices. The device has 13 bit accuracy over a 16g range. It also has functions for automatically detecting orientation and user “taps”. The Atmel microcontroller accesses the accelerometer by the SPI bus. Several signals are shared with the shift registers.

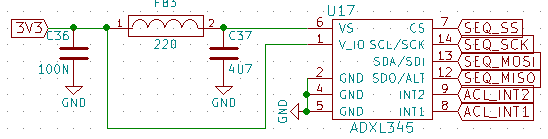
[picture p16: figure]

The accelerometer has also been wired with 2 direct interrupt pins for waking the Atmel controller if a movement is too extreme. The interrupt pins can be configured by SPI command. Sample rates for accelerometer can range from 1/10 to 3200 Hertz sample rates.

The SPI signals have been tied to SPI peripheral pins on the Atmel. ADXL345 Data sheet (http://www.analog.com/media/en/technical-documentation/data-sheets/ADXL345.pdf)

CANBUS Interface

The vehicle interface is provided by an STN1110, which is in many ways the same as an elm327. All three possible data networks have been provided ( CAN bus, j1850, ISO). The circuit has been optimized for low power usage. Many circuits that support operation are disabled while the STN1110 is in sleep or standby mode. CAN_POWERDOWN is driven by the STN1110 to perform the optimize role.

All inputs from the obd2 connector have been protected from static shocks. Also, it is possible to measure the vehicle's battery voltage from a function built into the STN1110. Physical switch, SW1 provides a 120 ohm CAN bus Terminator resistor for Medium and high-speed networks.

To use the vehicle interface CAN_RESET is taken high to bring the device out of reset. CAN_SLEEP is also taken high to make the device active. At this point CAN_TXD and CAN_RXD are used to communicate exclusively with the STN1110.

STN1110 Datasheets (http://www.scantool.net/scantool/downloads/97/stn1110-ds.pdf)

## CAN Start Up

The simple setup command set for the STN1110 for JLR vehicles is:

ate0,

ath1,

ats1,

atcaf0,

atspab

the line of misinformation (don’t trust below this line)

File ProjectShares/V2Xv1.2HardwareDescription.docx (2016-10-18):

V2X v1.2 Hardware Description

Author Jesse Banks

The design of the V2X board has an Atmel microcontroller at its heart. When the v2x board first receives power it should remain in an off state. the board has a singular button with dual purposes, starting power on the board and acting as a soft button for the sequencing chip (and vicariously the host computer software).

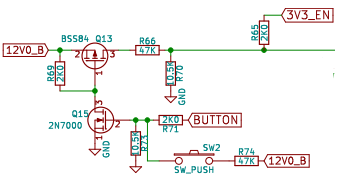
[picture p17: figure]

pressing the button will temporarily enable the 3V3 power supply, providing power to the atmel chip. The first action of the Atmel needs to be resetting shift registers to the default 0 state, then sending the 3V3_EN signal to keep the 3V3 Volt Power System alive. Once the button is released, the 3.3V power supply will shut off if the 3V3_EN is not pulled high by the Shift registers. There are more power modes described later.

The BUTTON signal is routed to the ATmega Port A0. It produces a positive logic signal (pin goes high on press).

SEQ_CHGPUMP operates a diode switched capacitor voltage doubler. this pin should toggle at >10Khz, and 100kHZ is better. Without running the charge pump the LEDs may not light.

SEQ_LED1, 2, 3 are all negative logic signals, a logic low causes the light to turn on. They can be pulsed at 10’s of Khz to create fading.

Shift registers

The method for controlling power switches and reset signals throughout the board is handled by a pair of 74HC595 serial shift registers. the shift registers use the ATmega SPI peripheral bus signals SCK and MOSI, along with dedicated clear and latch signals. Output Enable is signal “G” it is tied to ground so that the outputs are always on, and never high impedance.

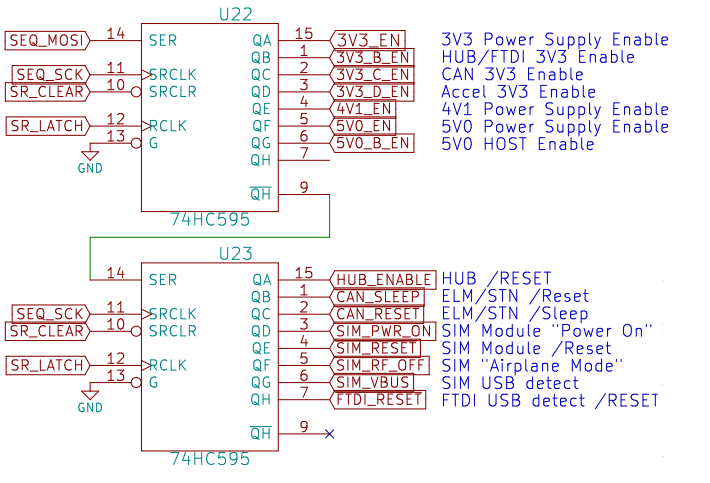
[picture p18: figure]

The shift register data sheet is here (http://www.mouser.com/ds/2/302/74HC_HCT595_Q100-269352.pdf)

The running state of SR_CLEAR is ‘1’ (not clear). The shift register reset procedure involves setting SR_CLEAR to ‘0’ (this clears all the shift registers) then cycling SR_LATCH 0->1->0 (moves the clear SR value to the output buffers) and setting SR_CLEAR to ‘1’ again. this operation loads all ‘0’s to the outputs and puts the control signals back in their default states.

SR_CLEAR

SR_LATCH

“1”

“0”

Power

Power switches allow for independently powering the ATmega, accelerometer, CAN bus controller, GSM/GPS modem, USB hub and FTDI along with the HOST computer itself. All of the power signals are grouped into the shift register closest to the ATmega, though this implies it receives the data sent last in the SR packet.

Power modes:

3V3_EN = ATmega

Plus 3V3_B_EN = HUB and FTDI

Plus 3V3_C_EN = CAN (Also needs 5V0_EN)

Plus 3V3_D_EN = Accelerometer

4V1_EN = GSM and GPS and ~2.3V SMS sleep for ATmega

5V0_EN = CAN

Plus 5V0_B_EN = HOST

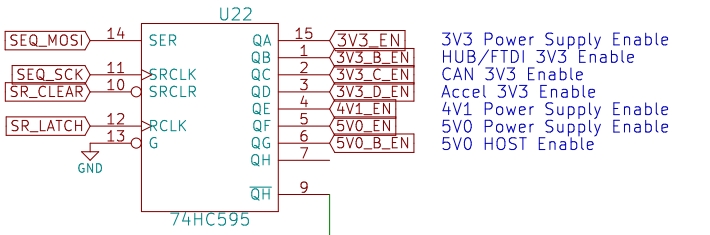
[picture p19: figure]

HOST Power

A ‘wake” event may triggered by the real time clock alarm, button press, or GSM/SMS received. The 5V0_EN signal is set high to start the 5volt power supply, U11. After a short delay (100ms guess), the 5V0_B_EN signal is set high to provide the host with power (5V0_B) through power switch U12.

Normal usage has the power for a Rpi2B HOST being delivered by USB cable from P8 mounted to the bottom side of the V2X PCB. The HOST could also be beaglebone, minnowmax, Rpi 1, etc.

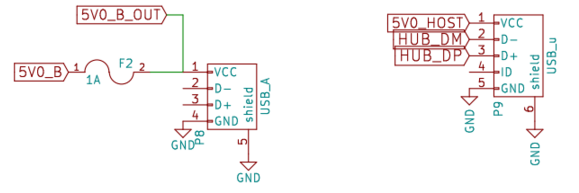
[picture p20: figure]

While 5V0_B is powered, HOST_SC can be monitored to determine if the is causing a short circuit, setting the poly fuse open. if HOST_SC is read as a logic ‘1’ the host is receiving power. A logic ‘0’ indicates the fuse is protecting the power supply. P9 is USB back from the HOST.

Once the HOST is started the ATmega receives AT commands (serail from FTDI or USB from HUB) that allows the HOST to modify the power modes (maybe just envoke canned sequences).

Enable and Reset signals

Most of the reset and sleep signals are grouped into the shift register farthest from the ATmega, this implies it receives the data sent first in the SR packet.

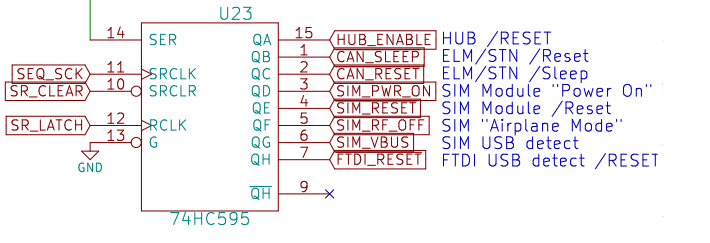
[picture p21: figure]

HUB ENABLE - Likely not used, routes to R18/R19 switch. Default config (R19=JMP) has the 5V0_HOST (USB Vbus) signal perform this action automatically.

CAN_SLEEP

External sleep control input. When enabled in firmware, puts the device into low - power sleep mode. Polarity of this pin can be configured in firmware; default configuration is active low. Internal pull-up to VDD is enabled by default, but can be disabled in firmware. When STN11xx senses a logic low on the SLEEP pin, it immediately aborts any OBD reception in progress, or monitoring command that is active at the time, and prints the command prompt. It then monitors the SLEEP input and enters the Power Save mode if the minimum low time (specified by the STSLXST command) is satisfied.

CAN_RESET

Device reset input. A logic low pulse (min 2μs) on this pin will reset the device. Apply a continuous logic low to hold the device in reset.

SIM_PWR_ON

The SIM5320 module expects a negative pulse to start the module. Q16 inverts a positive pulse to create this signal. This way a positive pulse from the shift register creates the signal the SIM is expecting. Also, the Shift register default 0 state should not trigger the SIM module to start falsely.

This circuit makes SIM_PWR_ON become SIM_PWR_ON

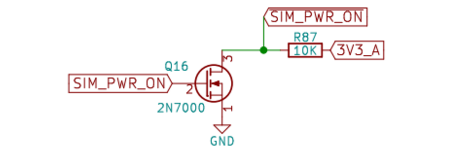
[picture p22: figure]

Here is a quick clip of the SIM module data sheet:


SIM_RESET


Should be high to operate the SIM5320 module. Only necessary to use as reset command if SIM stops responding to AT commands.

SIM_RF_OFF (GPIO4)

Positive logic RF operation control. A low signal causes the module to stop transmitting to observe “being on an airplane.” Set signal High for normal opperation

SIM_VBUS

Likely not used, routes to R10/R11 switch. The signal routing controls SIM_USB_DET which the SIM5320 uses to detect USB attachment. Default config (R11=JMP) has the HUB_PWR_PRT2 (Hub port active status) signal will perform this action automatically.

/FTDI_RESET

Likely not used, routes to R2/R3 switch. The signal routing controls /RESET pin on FT4232 which is used to detect USB attachment. Default config (R3=JMP) has the HUB_PWR_PRT2 (Hub port 2 status) signal will perform this action automatically.

SIM_WAKE is the only enable signal driven by the shift register closest to the ATmega. The signal wakes the GSm module from sleep.

USB Data

HOST Control of the V2X is handled completely over USB. As it enters the board it hits a 2 port hub. the hub sends the signals to the SIM5320 module and the FDTI4232 or ATmega through jumper settings on P22 (2x4 pin header)

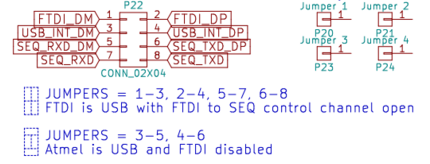
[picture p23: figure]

A goal of the ATmega firmware is to replace the FTDI with it’s own multipoint USB device inside the ATmega. both configurations should operate effectively the same as used by the HOST.

Both configurations make use of the 5 endpoint interface provided by the SIM5320 module. they provide GPS, modem and SMS information, with a simple relay through the USB hub.

The other 3 roles are Accelerometer, CAN and power sequencing control. we would use the FTDI as a plug-n-play 3-port serial pass through device until the atmel drivers are loaded.

With the FTDI in use, the CAN communications use one of the serial endpoints in the FT4232. the ATmega uses one channel to pass motion data and receive accelerometer config data (sample rate). A second serial endpoint is used to carry the power sequencer AT command interface.

If the FTDI is bypassed the ATmega pins that proved the serial command path to the FTDI become the USB data pins. The firmware will have to create a passthrough to the CAN device just as the FTDI did. And have two other endpoints for the ACL and SEQ command interfaces.

P22

JUMPERS

HOST

HUB

ATMEL

FTDI

USB

SERIAL

USB/SERIAL

USB

USB

CAN

U21 BUFFER

SERIAL

SERIAL

CONTROL

SERIAL

Serial Data

The ATmega is serially connected to the SIM5320 module, FTDI, and the CAN controller (STN1110). This system has multiple options for configuration. The variation is to support removing the FTDI from the system.

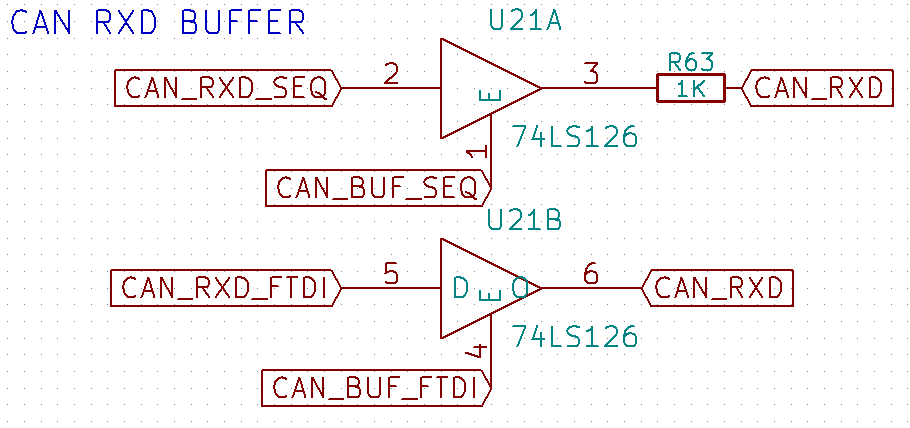
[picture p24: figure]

If the FTDI is used in the system, the ATmega has to control the signal routing for the CAN device. CAN_RXD_SEQ and CAN_RXD_FTDI are mutually exclusive signals. they each control the output enable signal to the CAN device receive pin. the signals should not both be high as the outputs of two buffers will fight. R63 is in place to keep them from hurting each other. the signal from the FTDI will win if both buffer outputs are active at the same time.

In active operation the HOST will be speaking to the CAN device to snoop the car. it will also be speaking to the ATmega through parallel channels for; gather accelerometer data and issue commands to the “power sequencer” function in the ATmega. this architecture was chosen to create easy differ entiation through unique USB endpoints.

If the FTDI is bypassed the ATmega will be performing the functions of the FTDI. It will be creating 3 “serial” endpoints for the HOST in with the same appearance to the host. The CAN serial buffer can be hard set to enable only the ATmega and disable the FTDI TXD.

The ATmega will change rolls when the host is on and off, acting as a serial pass through to the HOST, or it will activate the CAN controller periodically to snoop for ignition detection. The accelerometer and Power sequencer USB endpoint stay completely inside the ATmega.

SIM5320

The SIM5320 gets its subscription information from a sim card just like any other cell phone. The sim card slot has a switch for detecting when the card is inserted. The SIMCARD signal, Port D5, uses negative logic. When the pin is high there is no sim card in the socket. The pin should be configured with a pullup resistor, as an inserted card will close a switch to ground. For highest power efficiency the port-pullup should only be enabled several microseconds before a reading is taken, and disabled immediately afterward.

The GPS System is backed up by a super capacitor for rapid satellite acquisition. First acquisition can take 30+ seconds or more, subsequent acquisitions should be <1 second. The super capacitor should keep the clock running for 5-10 hours based on limited info.

The primary means of control is by USB connection. Through the USB are five virtual comports.

Simcard operation should be handled automatically. Card Logic voltage detection is also automatic.

the line of misinformation (don’t trust below this line)

http://www.analog.com/media/en/technical-documentation/data-sheets/ADXL345.pdf



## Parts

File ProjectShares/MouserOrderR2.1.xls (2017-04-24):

V2X_R2.1
Mouser # | Mfr. # | Manufacturer | Customer # | Description | RoHS | Lifecycle | Order Qty. | Price (USD) | Ext.: (USD)
611-PTS645VK392 | PTS645VK39-2 LFS | C&K Components | SW2 | Tactile Switches | RoHS Compliant |  | 1 | $0.26 | $0.26
595-LM339ADR | LM339ADR | Texas Instruments | U1 | Analog Comparators Quad Diff A Grade | RoHS Compliant |  | 1 | $0.35 | $0.35
942-IRF9335TRPBF | IRF9335TRPBF | Infineon | Q11, 12 | MOSFET 1 P-CH -30V HEXFET 59mOhms 4.7nC | RoHS Compliant |  | 2 | $0.57 | $1.14
863-SMMBT3904LT1G | SMMBT3904LT1G | ON Semiconductor | Q1,2,3,5 | Bipolar Transistors - BJT SS GP XSTR SPCL TR | RoHS Compliant |  | 4 | $0.28 | $1.12
863-MMQA5V6T3G | MMQA5V6T3G | ON Semiconductor | U23 | ESD Suppressors / TVS Diodes SC74 QUAD ARRAY 5.6V | RoHS Compliant |  | 1 | $0.379 | $0.38
863-MMBT3906LT1G | MMBT3906LT1G | ON Semiconductor | Q6 | Bipolar Transistors - BJT 200mA 40V PNP | RoHS Compliant |  | 1 | $0.10 | $0.10
863-LM317MBSTT3G | LM317MBSTT3G | ON Semiconductor | U4 | Linear Voltage Regulators 500mA ADJ 1.2-37V Positive | RoHS Compliant |  | 1 | $0.84 | $0.84
855-M20-9980346 | M20-9980346 | Harwin | PDI1 | Headers & Wire Housings 03+03 DIL VERTICAL PIN HEADER TIN | RoHS Compliant |  | 1 | $0.24 | $0.24
821-TS4148-0805-RY | TS4148RY | Taiwan Semiconductor | D1,2,3,4,5,9 | Diodes - General Purpose, Power, Switching SWITCHING DIODE | RoHS Compliant By Exemption |  | 6 | $0.114 | $0.68
81-LQW18CNR12J00D | LQW18CNR12J00D | Murata | L4 | Fixed Inductors 0603 120nH +/-5% 1100mA DCR .085ohm |  |  | 1 | $0.53 | $0.53
81-GRM21BR71C475KA73 | GRM21BR71C475KA73L | Murata | C8 | Multilayer Ceramic Capacitors MLCC - SMD/SMT 0805 4.7uF 16volts X7R 10% | RoHS Compliant |  | 1 | $0.44 | $0.44
81-GRM1885C1H9R0DA1D | GRM1885C1H9R0DA01D | Murata | C53,54 | Multilayer Ceramic Capacitors MLCC - SMD/SMT 0603 9.0pF 50volts C0G +/-0.5pF | RoHS Compliant |  | 2 | $0.10 | $0.20
815-S07AIG-32.76891T | ABS07AIG-32.768kHz-9-1-T | ABRACON | X3 | Crystals 32.768kHz AECQ200 9pF 10ppm -40C +125C | RoHS Compliant | New Product | 1 | $0.70 | $0.70
815-AWSCR-24.00MTD-T | AWSCR-24.00MTD-T | ABRACON | X2 | Resonators 24 MHz | RoHS Compliant By Exemption |  | 1 | $0.39 | $0.39
815-AWSCR-16.00MTD-T | AWSCR-16.00MTD-T | ABRACON | X1 | Resonators 16 MHz | RoHS Compliant By Exemption |  | 1 | $0.39 | $0.39
815-APAMPS-106 | APAMPS-106 | ABRACON | W1 | Antennas 1575.42MHz BW 10MHz VWSR 1.5:1 Max. | RoHS Compliant By Exemption |  | 1 | $16.48 | $16.48
810-MPZ1608S221ATA00 | MPZ1608S221ATA00 | TDK | FB1,2,3,4 | Ferrite Beads 220ohms 2.2A 50mOhms 0603 Ferrite Chip | RoHS Compliant |  | 4 | $0.10 | $0.40
810-C1608X7R1E104K | C1608X7R1E104K080AA | TDK |  | Multilayer Ceramic Capacitors MLCC - SMD/SMT 0603 0.1uF 25volts X7R 10% | RoHS Compliant | NRND | 21 | $0.03 | $0.63
80-C0603C331J5G | C0603C331J5GACTU | KEMET | C26 | Multilayer Ceramic Capacitors MLCC - SMD/SMT 50volts 330pF C0G 5% | RoHS Compliant |  | 1 | $0.10 | $0.10
806-KUSBEX-SMT2AS1N | KUSBEX-SMT2-AS1N-B30TR | Kycon | P3 | USB Connectors TYPE A USB SMT SOCKET | RoHS Compliant |  | 1 | $1.66 | $1.66
798-ZX62D-B-5PA830 | ZX62D-B-5PA8(30) | Hirose Electric | P16 | USB Connectors 5P RECEPTACLE | RoHS Compliant | New Product | 1 | $0.70 | $0.70
77-VJ0805Q151JXAAC | VJ0805Q151JXAAC | Vishay | C51 | Multilayer Ceramic Capacitors MLCC - SMD/SMT 150pF 50volts 5% | RoHS Compliant |  | 1 | $0.10 | $0.10
77-VJ0603Y561KXACBC | VJ0603Y561KXACW1BC | Vishay | C3,4 | Multilayer Ceramic Capacitors MLCC - SMD/SMT 0603 560pF 50volts X7R 10% | RoHS Compliant |  | 2 | $0.10 | $0.20
77-VJ0603Y103KXACBC | VJ0603Y103KXACW1BC | Vishay | C13,17,22 | Multilayer Ceramic Capacitors MLCC - SMD/SMT 0603 0.01uF 50volts X7R 10% | RoHS Compliant |  | 3 | $0.06 | $0.18
77-VJ0603D471KXXAJ | VJ0603D471KXXAJ | Vishay | C50 | Multilayer Ceramic Capacitors MLCC - SMD/SMT 0603 470pF 25V C0G 10% HI FREQ | RoHS Compliant |  | 1 | $0.20 | $0.20
77-VJ0603A560JXACBC | VJ0603A560JXACW1BC | Vishay | C48 | Multilayer Ceramic Capacitors MLCC - SMD/SMT 0603 56pF 50volts C0G 5% | RoHS Compliant |  | 1 | $0.06 | $0.06
771-74HC595D-Q100 | 74HC595D-Q100,118 | Nexperia | U18 | Counter Shift Registers 8 Bit Par-Ser Out 6V | RoHS Compliant |  | 1 | $0.48 | $0.48
71-CRCW0603-866-E3 | CRCW0603866RFKEA | Vishay | R20 | Thick Film Resistors - SMD 1/10watt 866ohms 1% | RoHS Compliant By Exemption |  | 1 | $0.10 | $0.10
71-CRCW0603-8.87K-E3 | CRCW06038K87FKEA | Vishay | R4 | Thick Film Resistors - SMD 1/10watt 8.87Kohms1% 1% | RoHS Compliant By Exemption |  | 1 | $0.10 | $0.10
71-CRCW0603-4.7K-E3 | CRCW06034K70FKEA | Vishay | R29 | Thick Film Resistors - SMD 1/10watt 4.7Kohms 1% | RoHS Compliant By Exemption |  | 1 | $0.10 | $0.10
71-CRCW0603-374-E3 | CRCW0603374RFKEA | Vishay | R19 | Thick Film Resistors - SMD 1/10watt 374ohms 1% | RoHS Compliant By Exemption |  | 1 | $0.10 | $0.10
71-CRCW0603-330-E3 | CRCW0603330RFKEA | Vishay | R61,66 | Thick Film Resistors - SMD 1/10watt 330ohms 1% | RoHS Compliant By Exemption |  | 2 | $0.10 | $0.20
71-CRCW0603-24K-E3 | CRCW060324K0FKEA | Vishay | R38,44 | Thick Film Resistors - SMD 1/10watt 24Kohms 1% | RoHS Compliant By Exemption |  | 2 | $0.10 | $0.20
71-CRCW0603-240-E3 | CRCW0603240RFKEA | Vishay | R27 | Thick Film Resistors - SMD 1/10watt 240ohms 1% | RoHS Compliant By Exemption |  | 1 | $0.10 | $0.10
71-CRCW0603-22.1-E3 | CRCW060322R1FKEA | Vishay | R69,70,71 | Thick Film Resistors - SMD 1/10watt 22.1ohms 1% | RoHS Compliant By Exemption |  | 3 | $0.10 | $0.30
71-CRCW0603-2.0K-E3 | CRCW06032K00FKEA | Vishay | R39,45 | Thick Film Resistors - SMD 1/10watt 2.0Kohms 1% | RoHS Compliant By Exemption |  | 2 | $0.10 | $0.20
71-CRCW0603-12K-E3 | CRCW060312K0FKEA | Vishay | R55 | Thick Film Resistors - SMD 1/10watt 12Kohms 1% | RoHS Compliant By Exemption |  | 1 | $0.10 | $0.10
71-CRCW0603-10K-E3 | CRCW060310K0FKEA | Vishay |  | Thick Film Resistors - SMD 1/10watt 10Kohms 1% | RoHS Compliant By Exemption |  | 20 | $0.043 | $0.86
71-CRCW0603-100K-E3 | CRCW0603100KFKEA | Vishay | R33,34 | Thick Film Resistors - SMD 1/10watt 100Kohms 1% | RoHS Compliant By Exemption |  | 2 | $0.10 | $0.20
71-CRCW0603-10.5K-E3 | CRCW060310K5FKEA | Vishay | R40 | Thick Film Resistors - SMD 1/10watt 10.5Kohms 1% | RoHS Compliant By Exemption |  | 1 | $0.10 | $0.10
71-CRCW0603-1.0K-E3 | CRCW06031K00FKEA | Vishay | R5,6,10,32,35 | Thick Film Resistors - SMD 1/10watt 1.0Kohms 1% | RoHS Compliant By Exemption |  | 5 | $0.10 | $0.50
710-150080RS75000 | 150080RS75000 | Wurth Electronics | D13 | Standard LEDs - SMD WL-SMCW SMDMono TpVw Waterclr 0805 Red | RoHS Compliant |  | 1 | $0.17 | $0.17
710-150080GS75000 | 150080GS75000 | Wurth Electronics | D11 | Standard LEDs - SMD WL-SMCW SMDMono TpVw Waterclr 0805 Green | RoHS Compliant |  | 1 | $0.17 | $0.17
710-150080BS75000 | 150080BS75000 | Wurth Electronics | D12 | Standard LEDs - SMD WL-SMCW SMDMono TpVw Waterclr 0805 Blue | RoHS Compliant |  | 1 | $0.17 | $0.17
667-ERJ-3GEYJ221V | ERJ-3GEYJ221V | Panasonic | R63 | Thick Film Resistors - SMD 0603 220ohms 5% AEC-Q200 | RoHS Compliant By Exemption |  | 1 | $0.10 | $0.10
667-ERJ-3EKF1200V | ERJ-3EKF1200V | Panasonic | R22,26,36 | Thick Film Resistors - SMD 0603 120ohms 1% AEC-Q200 | RoHS Compliant By Exemption |  | 3 | $0.149 | $0.45
667-EEE-FT1V101AP | EEE-FT1V101AP | Panasonic | C19 | Aluminum Electrolytic Capacitors - SMD 100uF 35volts 6.3x5.8mm SMD | RoHS Compliant |  | 1 | $0.70 | $0.70
667-10SVPE220M | 10SVPE220M | Panasonic | C14,21 | Aluminum Organic Polymer Capacitors 10volts 220uF ESR 18mohm | RoHS Compliant |  | 2 | $2.46 | $4.92
653-A6SN-1104 | A6SN-1104 | Omron | SW1 | DIP Switches / SIP Switches 1P Knife-Edge, 2.3mm Slide SMT Raised-Act | RoHS Compliant |  | 1 | $1.36 | $1.36
652-SRP4020TA-5R6M | SRP4020TA-5R6M | Bourns | L1,2 | Fixed Inductors 5.6uH 20% SMD 4020 AEC-Q200 | RoHS Compliant |  | 2 | $1.17 | $2.34
621-SBR3U30P1-7 | SBR3U30P1-7 | Diodes Incorporated | D8,10 | Schottky Diodes & Rectifiers 3A 30V Ultralow VF | RoHS Compliant By Exemption |  | 2 | $0.49 | $0.98
621-B320A-F | B320A-13-F | Diodes Incorporated | D7 | Schottky Diodes & Rectifiers 20V 3A | RoHS Compliant By Exemption |  | 1 | $0.39 | $0.39
617-09551667812741 | 09551667812741 | HARTING | J1 | D-Sub Standard Connectors DSUB ML SMT ANG 9P PL3 WITH 4-40 UN | RoHS Compliant |  | 1 | $5.11 | $5.11
603-RC1210FR-07510RL | RC1210FR-07510RL | Yageo | R1,2 | Thick Film Resistors - SMD 510 OHM 1% | RoHS Compliant |  | 2 | $0.14 | $0.28
603-CC126KKX7R7BB106 | CC1206KKX7R7BB106 | Yageo | C24,30,31,55 | Multilayer Ceramic Capacitors MLCC - SMD/SMT 10uF 16V X7R 10% | RoHS Compliant By Exemption |  | 4 | $0.28 | $1.12
584-ADXL345BCCZ | ADXL345BCCZ | Analog Devices Inc. | U17 | Accelerometers 3-Axis Low g Digital-Output | RoHS Compliant By Exemption |  | 1 | $6.93 | $6.93
581-12063C475KAT2A | 12063C475KAT2A | AVX | C20,28 | Multilayer Ceramic Capacitors MLCC - SMD/SMT 25V 4.7uF X7R 1206 10% Tol | RoHS Compliant By Exemption |  | 2 | $0.55 | $1.10
581-06036C105MAT2A | 06036C105MAT2A | AVX | C5,9,10,11,34,35,46 | Multilayer Ceramic Capacitors MLCC - SMD/SMT 6.3V 1uF X7R 0603 20% Tol | RoHS Compliant |  | 7 | $0.10 | $0.70
581-06035A221J | 06035A221JAT2A | AVX | C15 | Multilayer Ceramic Capacitors MLCC - SMD/SMT 50V 220pF C0G 0603 5% Tol | RoHS Compliant |  | 1 | $0.10 | $0.10
579-USB2422/MJ | USB2422/MJ | Microchip | U16 | USB Interface IC | RoHS Compliant |  | 1 | $1.86 | $1.86
579-MCP2551-I/SN | MCP2551-I/SN | Microchip | U5 | CAN Interface IC Hi Spd CAN Transceiv | RoHS Compliant |  | 1 | $1.12 | $1.12
556-ATXMEGA128A4U-AU | ATXMEGA128A4U-AU | Microchip | U20 | 8-bit Microcontrollers - MCU 44TQFP, IND TEMP GREEN, 1.6-3.6V | RoHS Compliant |  | 1 | $4.82 | $4.82
538-47553-1001 | 47553-1001 | Molex | P24 | Memory Card Connectors ASSY FOR PUSH PUSH 6 PUSH 6 PIN SIM CONN. | RoHS Compliant |  | 1 | $2.67 | $2.67
530-142-0701-801 | 142-0701-801 | Cinch Connectivity Solutions | P22,23 | RF Connectors / Coaxial Connectors PC END MT JCK GLD .062" BOARD THICK | RoHS Compliant |  | 2 | $3.48 | $6.96
530-0ZCG0200AF2B | 0ZCG0200AF2B | Bel | F1 | Resettable Fuses - PPTC 2A 16V PPTC 1812 SMD | RoHS Compliant | New Product | 1 | $0.20 | $0.20
530-0ZCG0160BF2C | 0ZCG0160BF2C | Bel | F2 | Resettable Fuses - PPTC | RoHS Compliant |  | 1 | $0.17 | $0.17
512-FDC6326L | FDC6326L | Fairchild Semiconductor | U7,10 | Power Switch ICs - Power Distribution SSOT-6 LOAD SW 20V | RoHS Compliant |  | 2 | $0.64 | $1.28
512-BSS84 | BSS84 | Fairchild Semiconductor | Q7,8,10 | MOSFET SOT-23 P-CH ENHANCE | RoHS Compliant |  | 3 | $0.23 | $0.69
512-2N7002K | 2N7002K | Fairchild Semiconductor | Q4,9,15 | MOSFET 60V, 300mA N-Chan | RoHS Compliant |  | 3 | $0.27 | $0.81
511-SMBJ16A | SMBJ16A-TR | STMicroelectronics | D6 | ESD Suppressors / TVS Diodes 600W 16V Unidirect | RoHS Compliant |  | 1 | $0.48 | $0.48
511-LDK320M33R | LDK320M33R | STMicroelectronics | U11,12,13 | LDO Voltage Regulators POWER MANAGEMENT | RoHS Compliant | New Product | 3 | $0.64 | $1.92
511-ESDA25SC6 | ESDA25SC6 | STMicroelectronics | U2,3 | ESD Suppressors / TVS Diodes 25V 500W Unidirect | RoHS Compliant |  | 2 | $0.62 | $1.24
504-KR-5R5C104-R | KR-5R5C104-R | Eaton | C47 | Supercapacitors / Ultracapacitors .1F 5.5V EDLC Coin Cell Cyl | RoHS Compliant |  | 1 | $2.64 | $2.64
667-ERJ-3EKF8201V | ERJ-3EKF8201V | Panasonic | R47 | Thick Film Resistors - SMD 0603 8.2Kohms 1% AEC-Q200 | RoHS Compliant By Exemption |  | 1 | $0.149 | $0.15
667-ERJ-3EKF6202V | ERJ-3EKF6202V | Panasonic | R24 | Thick Film Resistors - SMD 0603 62Kohms 1% AEC-Q200 | RoHS Compliant By Exemption |  | 1 | $0.149 | $0.15
755-KTR03EZPF4702 | KTR03EZPF4702 | ROHM Semiconductor | R42,43,51-59 | Thick Film Resistors - SMD 0603 47Kohm 1% High VoltageAEC-Q200 | RoHS Compliant | New Product | 10 | $0.116 | $1.16
701-XRP6124ES0.5-F | XRP6124ES0.5-F | Exar | U8,9 | Switching Controllers PFET controllers w/ Cnstnt OnTime Cntrl | RoHS Compliant |  | 2 | $1.25 | $2.50
81-GRM21BR71A475KA3K | GRM21BR71A475KA73K | Murata | C16,23,27,37 | Multilayer Ceramic Capacitors MLCC - SMD/SMT 4.7uF 10Volts 10% | RoHS Compliant |  | 4 | $0.219 | $0.88
81-LQW18AN56NG00D | LQW18AN56NG00D | Murata | L3 | Fixed Inductors 56 NH 2% (R) | RoHS Compliant |  | 1 | $0.17 | $0.17
652-CR0603FX-2201ELF | CR0603-FX-2201ELF | Bourns | R3,21 | Thick Film Resistors - SMD 2.2K 1% 1/10W | RoHS Compliant By Exemption |  | 1 | $0.101 | $0.10

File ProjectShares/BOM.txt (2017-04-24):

504-KR-5R5C104-R|1
511-ESDA25SC6|2
511-LDK320M33R|3
511-SMBJ16A|1
512-2N7002K|3
512-BSS84|3
512-FDC6326L|2
530-0ZCG0160BF2C|1
530-0ZCG0200AF2B|1
530-142-0701-801|2
538-22-28-5023|1
538-47553-1001|1
556-ATXMEGA128A4U-AU|1
579-MCP2551-I/SN|1
579-USB2422/MJ|1
581-06035A221J|1
581-08052U560G|1
581-12063C475KAT2A|7
584-ADXL345BCCZ-R7|1
603-CC126KKX7R7BB106|4
603-CC603KRX7R7BB105|1
603-RC1210FR-07510RL|2
617-09551667812741|1
621-B320A-F|1
621-MMBT3906-F|1
621-SBR3U30P1-7|2
652-SRP4020TA-5R6M|2
653-A6SN-1104|1
656-DX4R005JJ2R1800|1
667-EEE-FT1V101AP|1
667-ERJ-3EKF1200V|3
701-XRP6124ES0.5-F|2
710-150080BS75000|1
710-150080GS75000|1
710-150080RS75000|1
710-875105244013|2
71-CRCW0603-1.0K-E3|5
71-CRCW0603-10.5k-E3|1
71-CRCW0603-100K-E3|2
71-CRCW0603-10K-E3|20
71-CRCW0603-12K-E3|1
71-CRCW0603-2.0k-E3|2
71-CRCW0603-2.2K-E3|2
71-CRCW0603-22.1-E3|3
71-CRCW0603-220-E3|1
71-CRCW0603-240-E3|1
71-CRCW0603-24k-E3|2
71-CRCW0603-330-E3|2
71-CRCW0603-374-E3|1
71-CRCW0603-4.7K-E3|1
71-CRCW0603-47k-E3|10
71-CRCW0603-62K-E3|1
71-CRCW0603-8.2K-E3|1
71-CRCW0603-8.87K-E3|1
71-CRCW0603-866-E3|1
771-74HC595D-Q100|1
77-VJ0603D471KXXAJ|1
77-VJ0603Y103KXACBC|3
77-VJ0603Y561KXACBC|2
77-VJ0805Q151JXAAC|1
806-KUSBEX-SMT2AS1N|1
80-C0603C331J5G|1
810-C1608X7R1E104K|21
810-MPZ1608S221ATA00|4
815-APAMPS-106|1
815-AWSCR-16.00MTD-T|1
815-AWSCR-24.00MTD-T|1
815-S07AIG-32.76891T|1
81-GRM1885C1H9R0DA1D|2
81-GRM188R71C105KA2J|6
81-LQG18HN47NJ00D|1
81-LQW18CNR12J00D|1
821-MMBT3904|4
821-TS4148-0805-RY|6
855-M20-9980346|1
863-LM317MBSTT3G|1
863-MMQA5V6T3G|1
942-IRF9335TRPBF|2
LM339ADR|1
PTS645VK39-2-LFS|1
ScacntoolOrder|1
AliExpressOrder|1
AmazonOrder|1

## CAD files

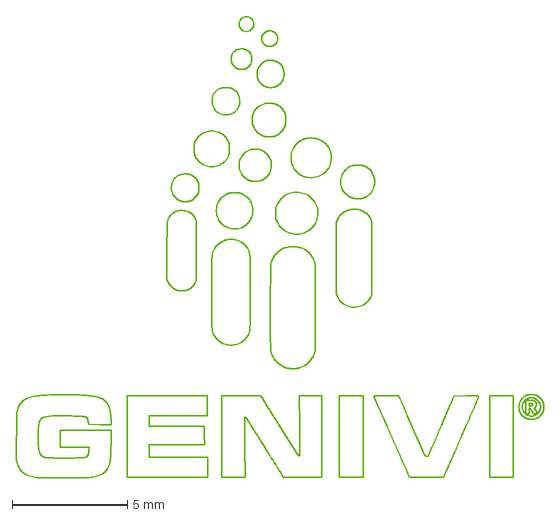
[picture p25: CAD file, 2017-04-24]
MakeFiles/GENIVI_Logo_Full.dxf
22.9 x 20.0 mm

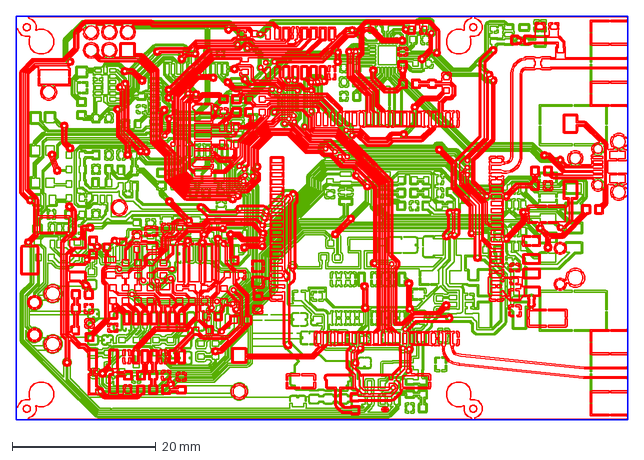
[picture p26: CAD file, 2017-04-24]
ProjectShares/V2X.dxf
85.0 x 56.0 mm

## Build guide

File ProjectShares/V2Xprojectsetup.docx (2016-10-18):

V2X Programmer's Guide

Brief: How to get the V2X project setup and ready to edit on your computer.

1. Go to http://www.atmel.com/tools/ATMELSTUDIO.aspx

Download the offline installer as a Guest if involvement is short. An account is not complicated if you will work on the project for some time. You will have to provide your email to get the installer (a link is sent).

2. Install Atmel Studio 7 and the USB drivers. This will require running the installer with “run as administrator” privileges. Be sure to use “Advanced view” when the question is asked.
3. GIT Clone the repo to a local project folder.

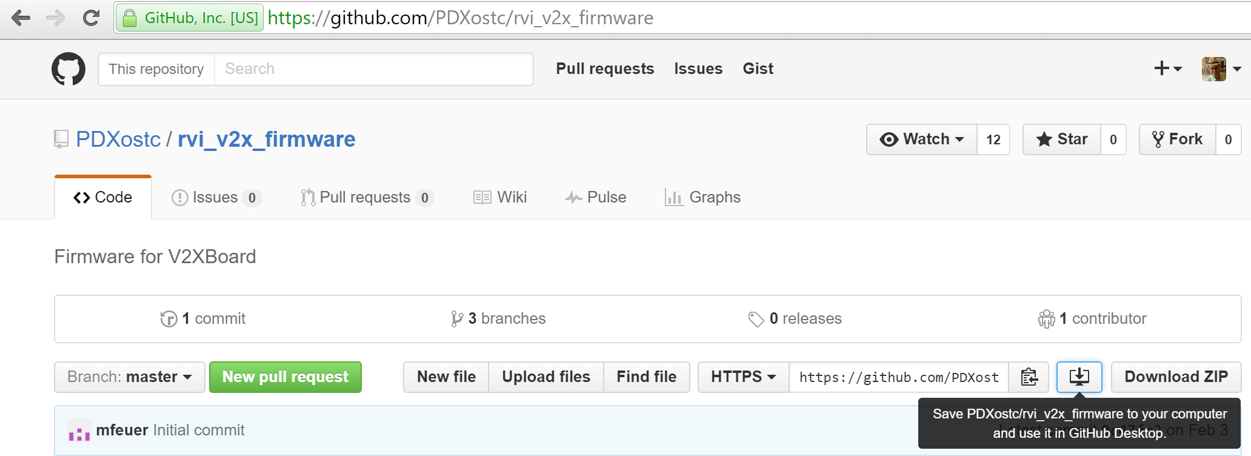
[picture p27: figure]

4. Switch to Develop branch of git repo.
5. Navigate into the repo \rvi_v2x_firmware\V2X_Firmware and open the V2X.cproj file.
6. Once the program launches, the ASF wizard should be displayed, select “V2X” from the Project pull down.

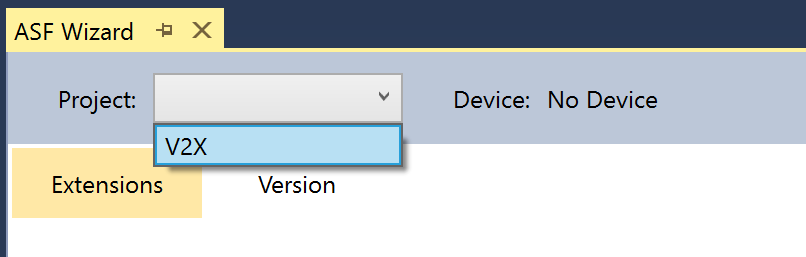
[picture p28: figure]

7. Click the version tab. Uncheck the Trigger upgrade box. A dialog will launch for confirmation.

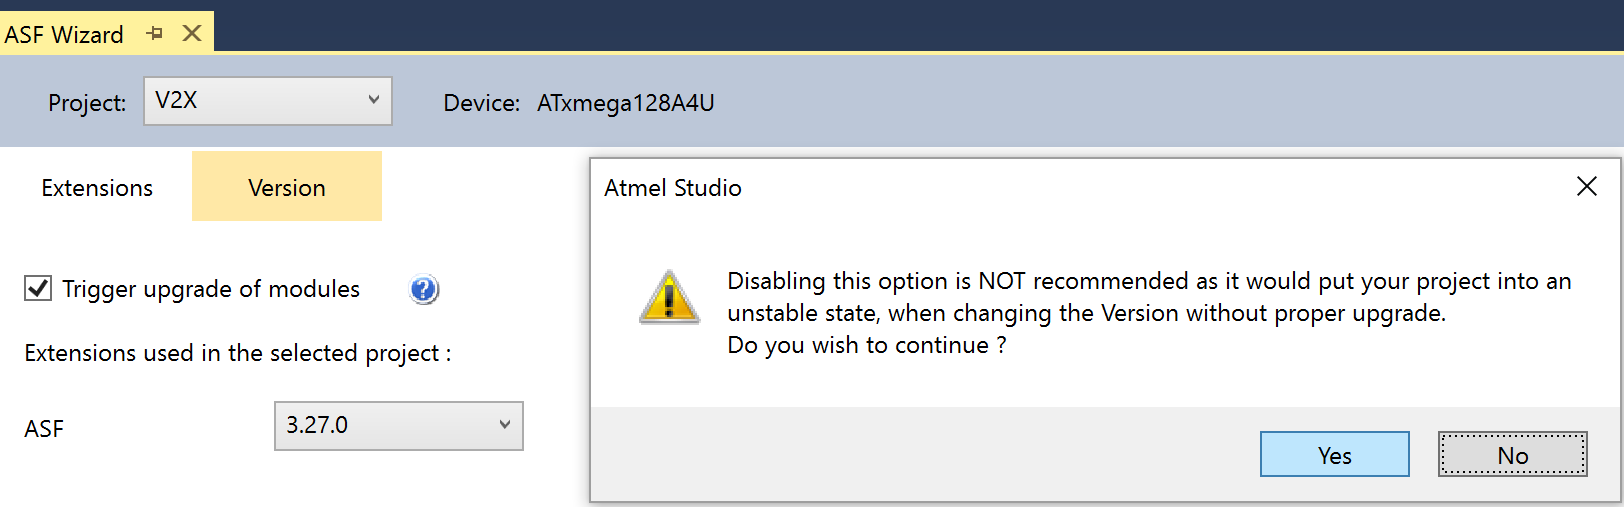
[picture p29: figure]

8. Downgrade the project by one ASF version.

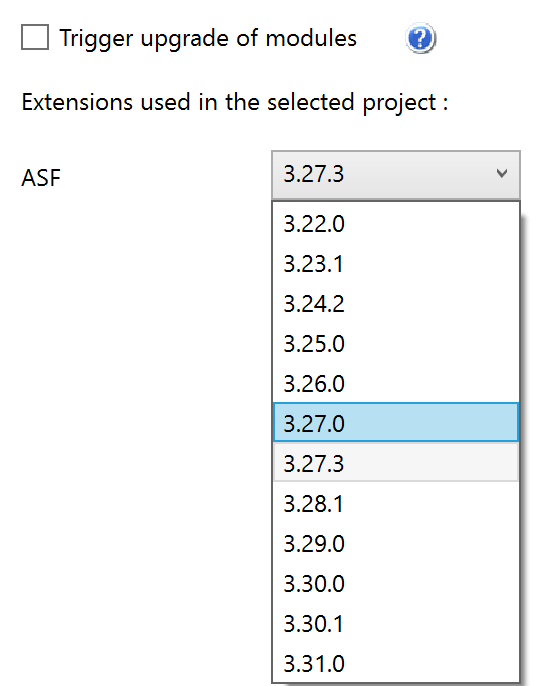
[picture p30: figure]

9. Check the Trigger Upgrade box then return the project to the current version. Click Upgrade.

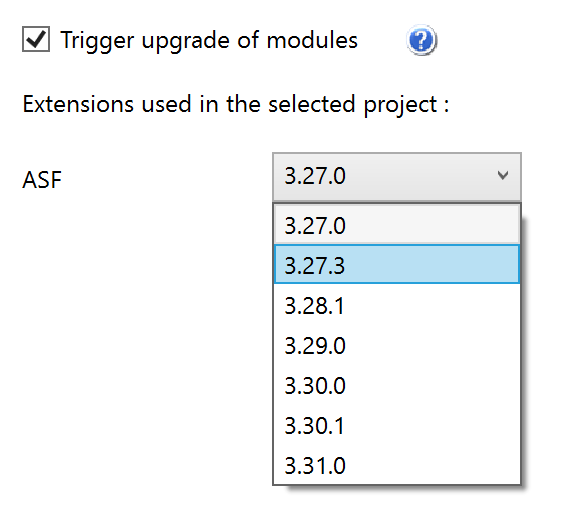
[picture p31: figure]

10. Follow the wizard, click “Next,” select “No,” click Finish. After the upgrade, there is no need to check the log. Click OK.

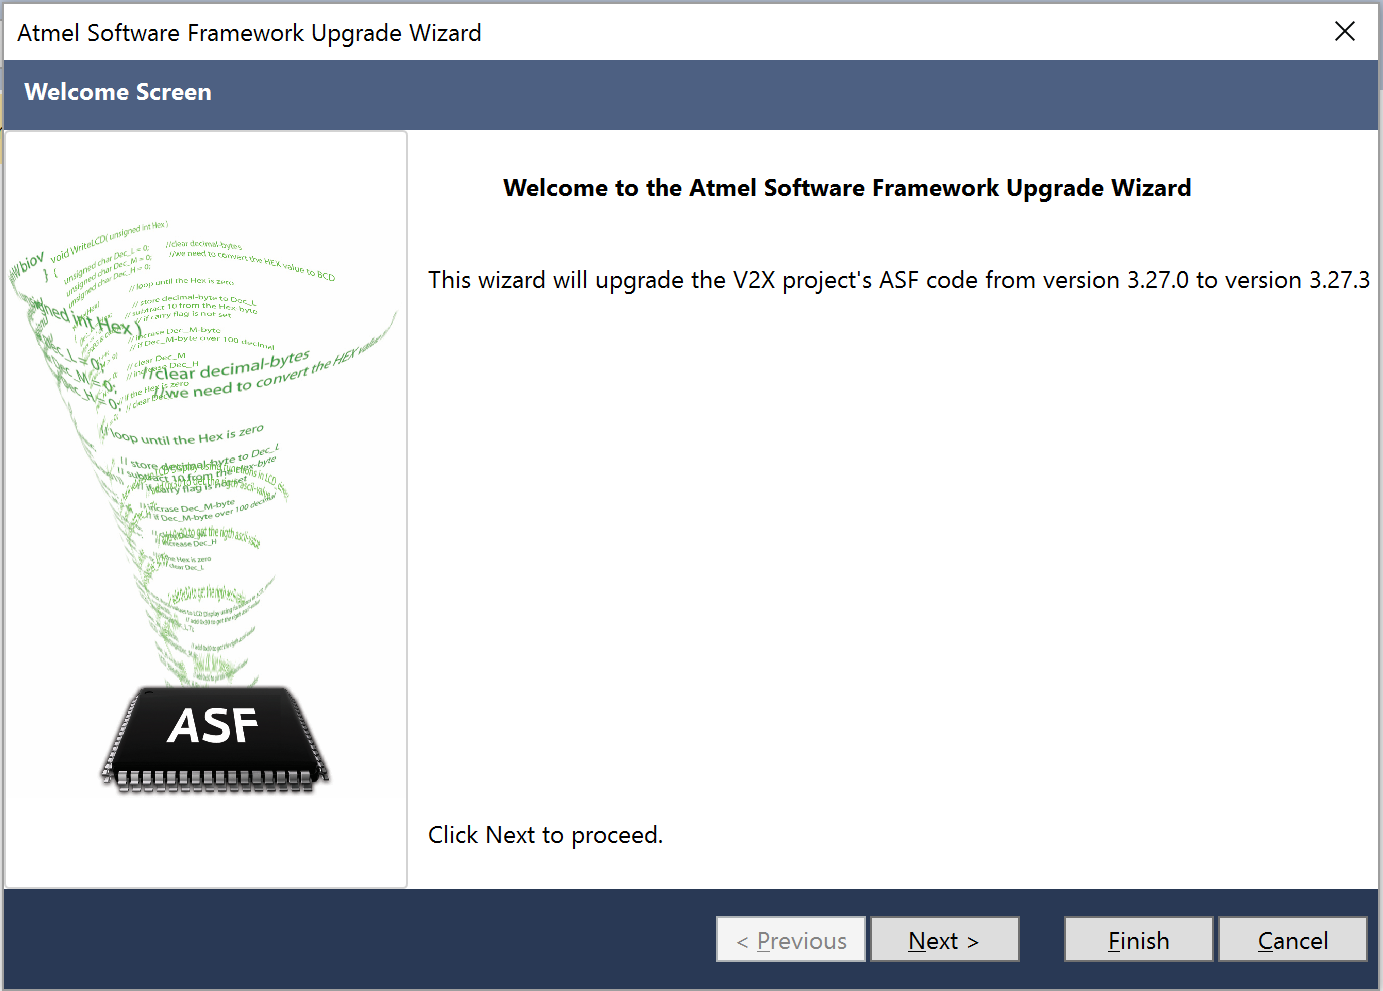
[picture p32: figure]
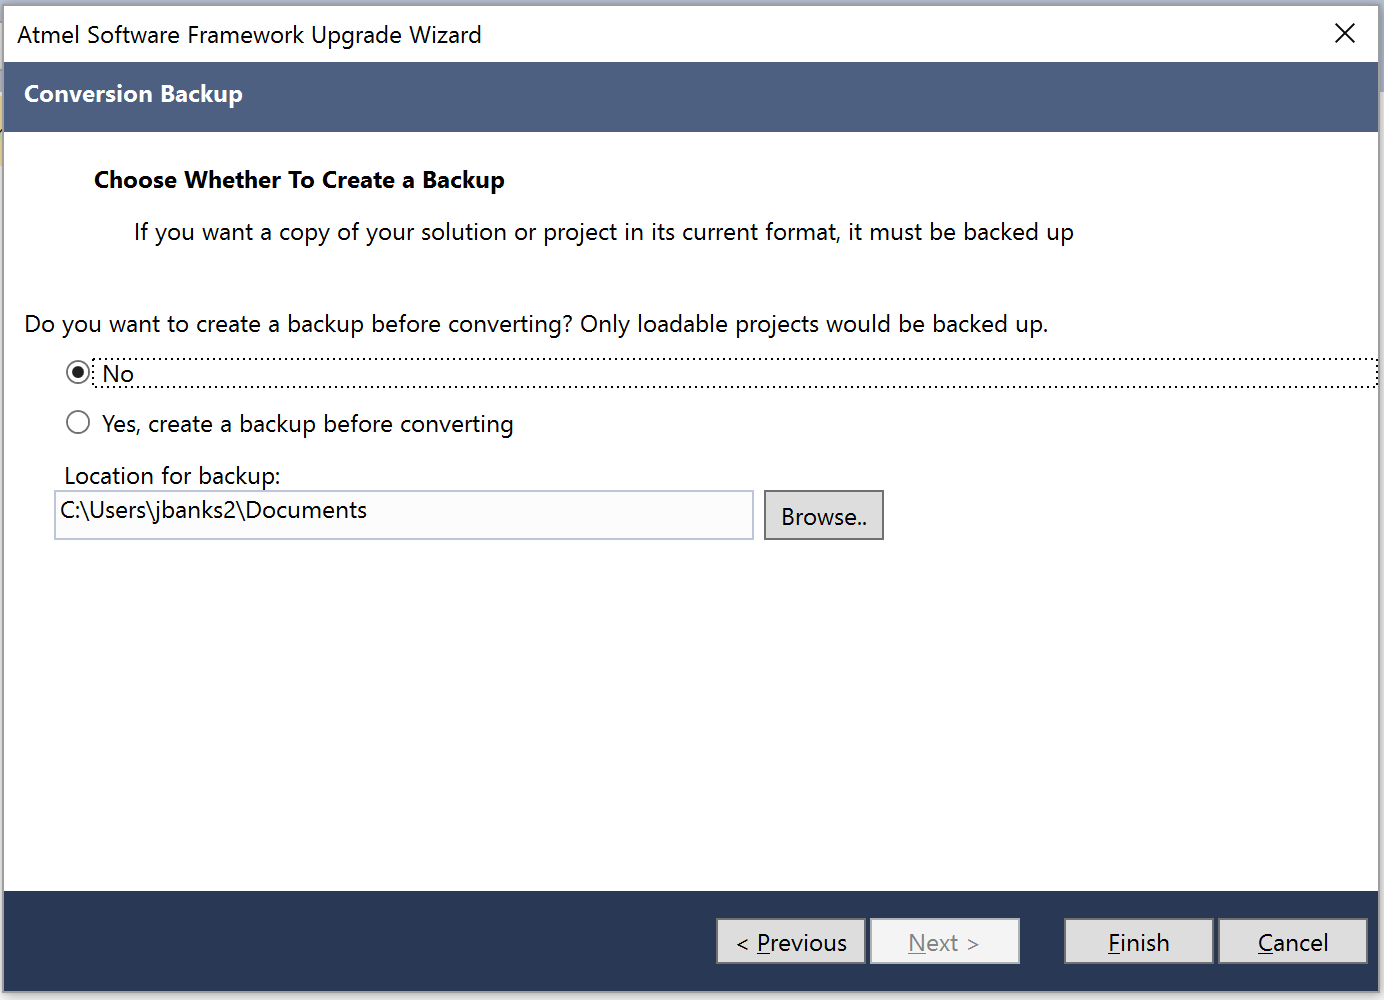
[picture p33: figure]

11. Navigate back to the Extension tab. Verify these modules are contained in the project:
  11.1. If not present, select corresponding module from the “Available modules” field in the left pane
    11.1.1. AC - Analog Comparator
    11.1.2. ADC - Analog to Digital converter
    11.1.3. Calendar Functionality (service)
    11.1.4. Chip Reset Cause Access (Common API) (service)
    11.1.5. CPU specific features (driver)
    11.1.6. Delay routines (service)
    11.1.7. DMA - Direct Memory Access (driver)
    11.1.8. GPIO - General purpose Input/Output (service)
    11.1.9. Interrupt management (Common API) (driver)
    11.1.10. IOPORT - General purpose I/O Service (service)
    11.1.11. IOPORT - Input/Output Port Controller (driver)
    11.1.12. Memory Control Access Interface (service)
    11.1.13. NVM - Non Volatile Memory (driver)
    11.1.14. NVM - Non volatile memory access (CommonAPI) (Driver)
      11.1.14.1. No_extmem
    11.1.15. PMIC - Programmable Multi-level Interrupt Controller (driver)
    11.1.16. PWM service using timer/counter (service)
    11.1.17. RTC - Real Time Counter (driver)
    11.1.18. Serial I/O - Host (component)
      11.1.18.1. USB
    11.1.19. Sleep Controller driver (driver)
    11.1.20. Sleep manager (service)
    11.1.21. SPI - Serial Peripheral Interface (driver)
    11.1.22. SPI - Serial Periferal Interface Master (Common API) (service)
      11.1.22.1. Standard_spi
    11.1.23. Standard serial I/O (stdio) (driver)
    11.1.24. System Clock Control (sevice)
    11.1.25. TC - Timer Counter (driver)
    11.1.26. USART - Serial interface (service)
    11.1.27. USART - Universal Synchronous/Asynchronous Reciever/Transmitter (driver)
    11.1.28. USB Device (service)
      11.1.28.1. Composite
    11.1.29. WDT - Watchdog timer (service)
  11.2. Click “ADD>>”  Note: Likely all necessary the modules will be in the “Selected Module” pane and only the sub-selection of “USB Device” and “Serial I/O - Host” will be incorrect.

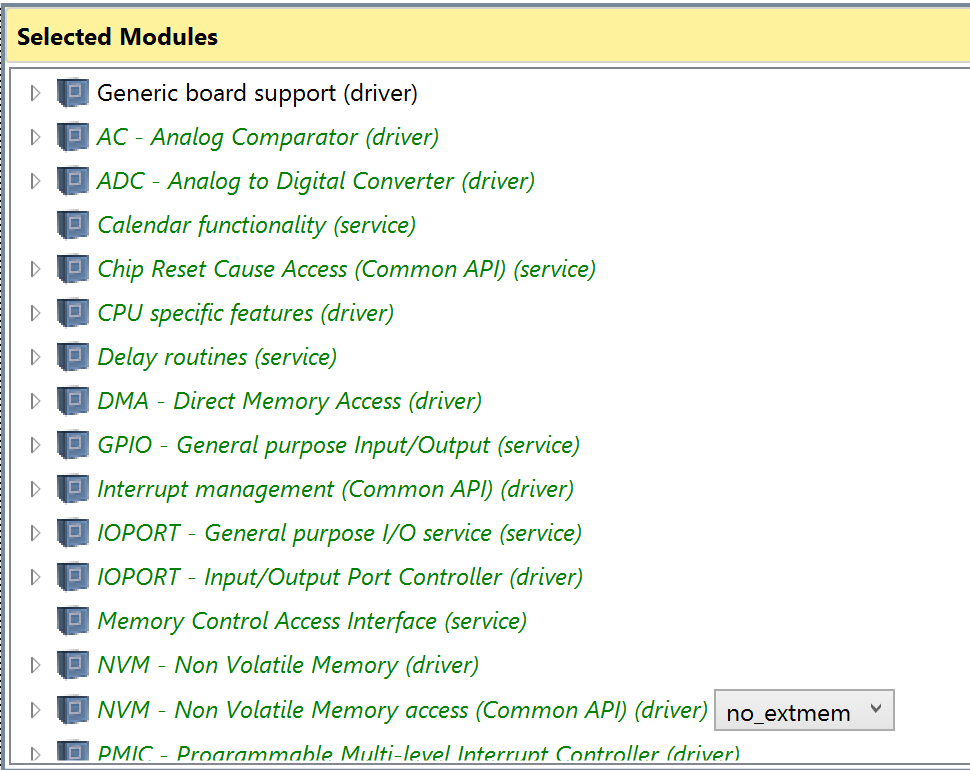
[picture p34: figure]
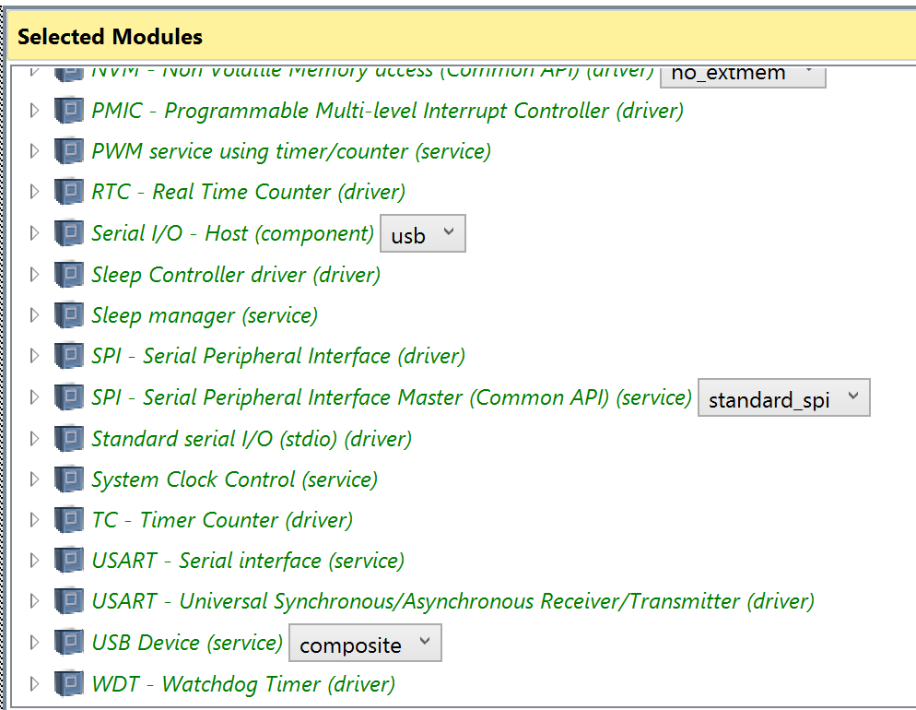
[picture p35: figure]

12. Click “Apply”, then “Ok” when a confirmation dialog appears.
13. Save the project then Exit the tool.

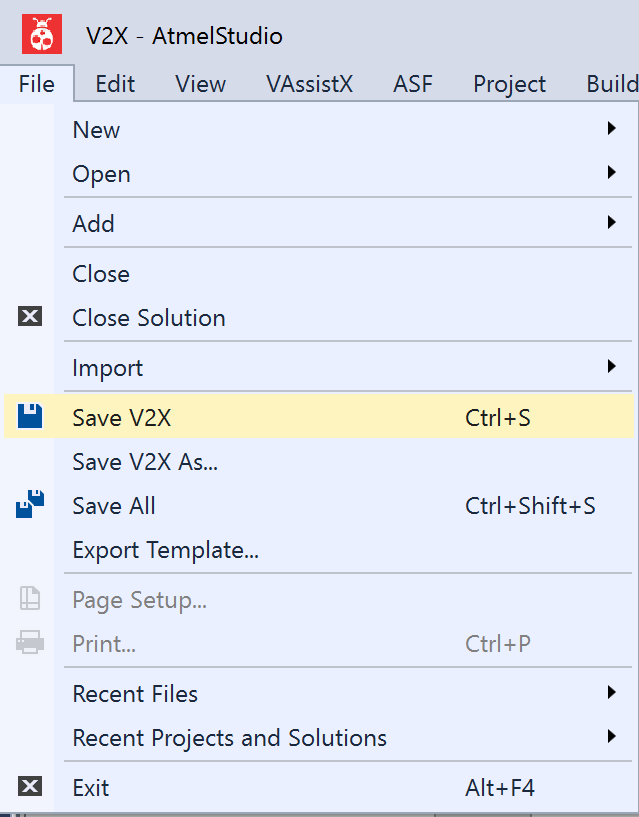
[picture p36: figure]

14. A popup dialog will ask to save the project. Click Yes. Click Save. the application will exit.

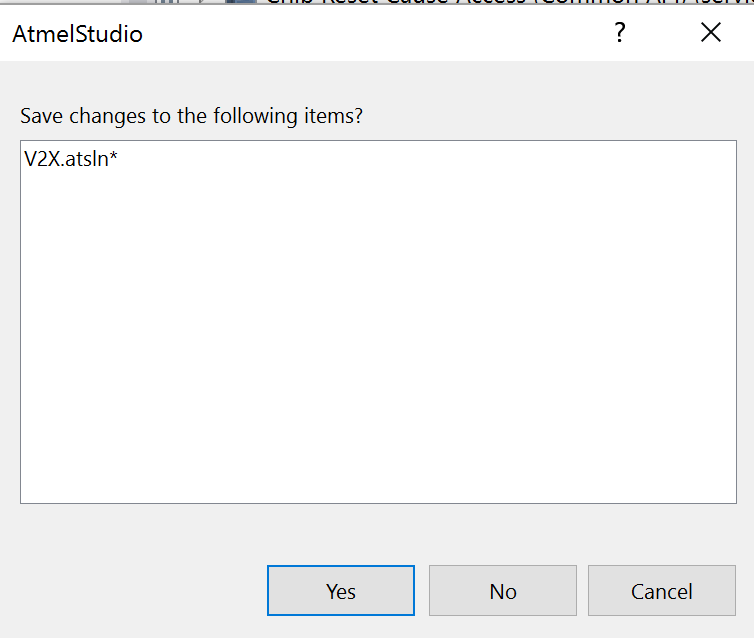
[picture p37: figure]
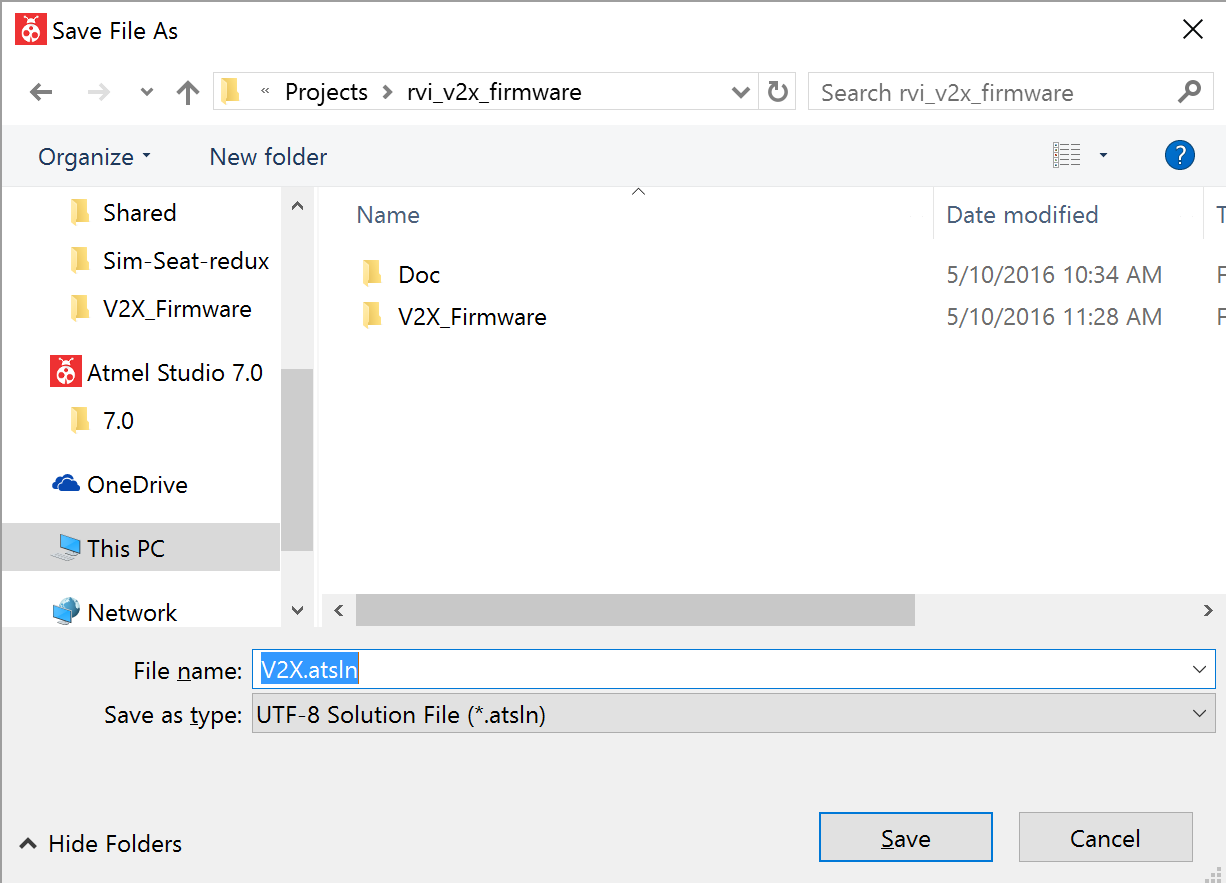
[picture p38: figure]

15. Navigate to \rvi_v2x_firmware\V2X_Firmware\src\V2X\extra_files copy the 3 files.

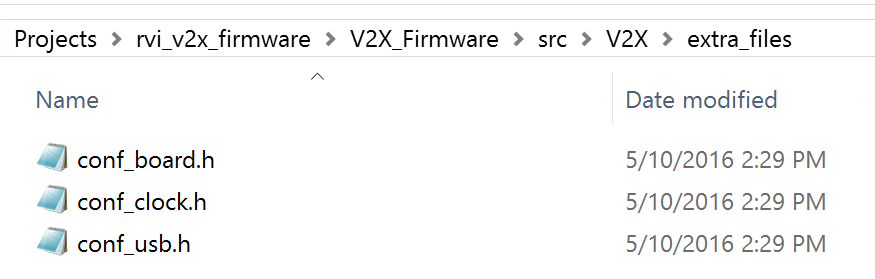
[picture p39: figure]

16. Navigate to \rvi_v2x_firmware\V2X_Firmware\src\V2X\extra_files paste the 3 files overwriting any conflicts.

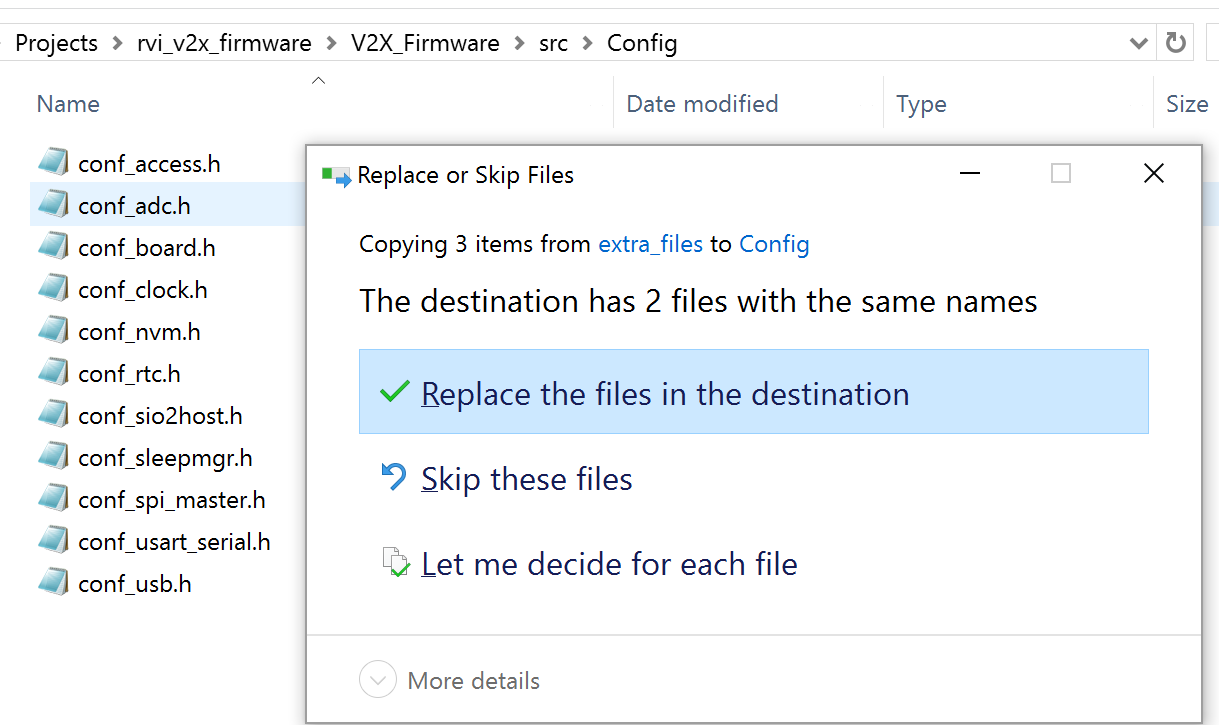
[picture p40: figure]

17. Launch the the V2X.atsln project file in \rvi_v2x_firmware\V2X_Firmware. Atmel Studio will start. The ASF wizard tab can be closed. The project should successfully build (F7).
18. Connect the V2X hardware to dragon, power and USB

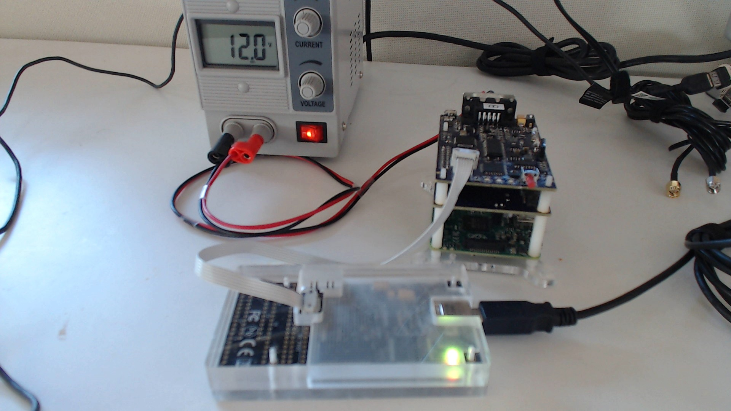
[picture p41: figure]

19. Plug in the AVR Dragon programmer by USB (drivers should auto install)
20. Use the menu Debug -> V2X Properties…

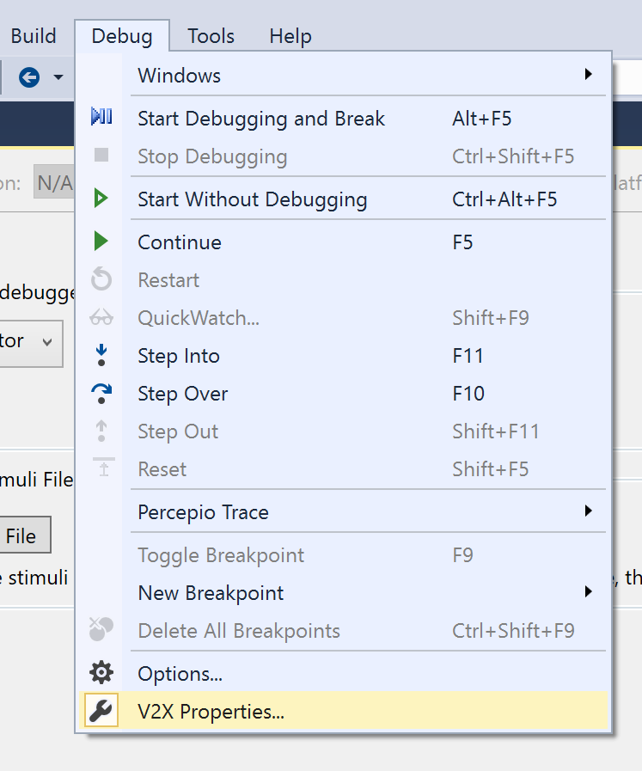
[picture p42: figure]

21. If the dragon installed properly it should appear in the list. Select it, click save from the buttons along the top. Close the tab.

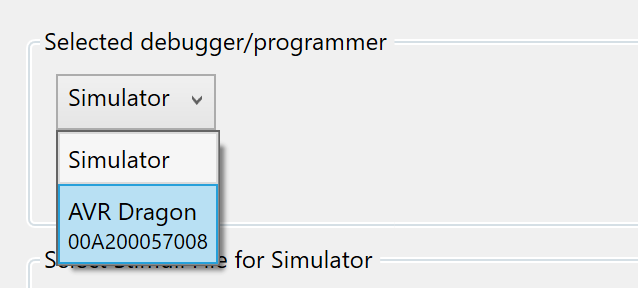
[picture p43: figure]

22. Verify the V2X hardware is powered on. If the V2X has never been installed before you will need to hold the button down while any programming operations are performed.
23. Select Device programming from the Tools menu.
24. Select the Dragon as the device, select the ATxmega128A4U from the drop down, PDI interface, then click Apply”

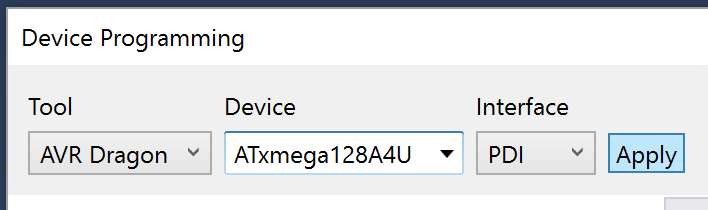
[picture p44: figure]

25. Hold the V2X button down and click device signature. If the chip is connected properly and operating the ID value 0x1E9746 will populate the Device Signature field and the Target Voltage field will also populate. If this test passes, close the window and move on. Failure discussion is beyond the scope of this document.

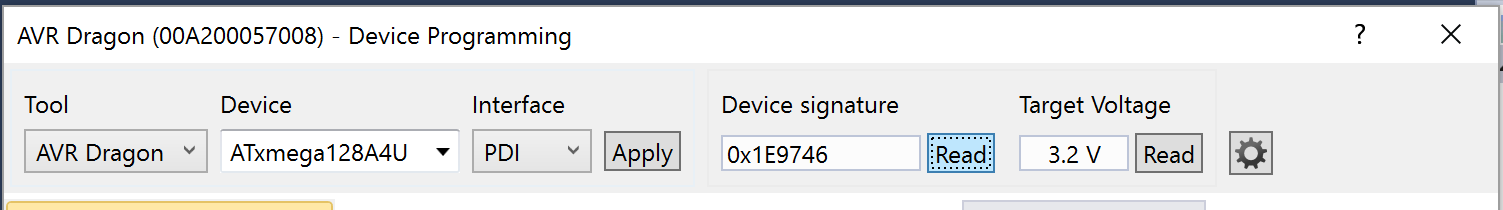
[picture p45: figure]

26. Install the firmware to the V2X hardware. Again, you may need to hold the V2X button down to install the firmware
27. The V2X should now mount a USB2 hub, 3 ports labled V2X and 5 ports labeled SIM5320.

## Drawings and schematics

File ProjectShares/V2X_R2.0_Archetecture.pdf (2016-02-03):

## Cloud server

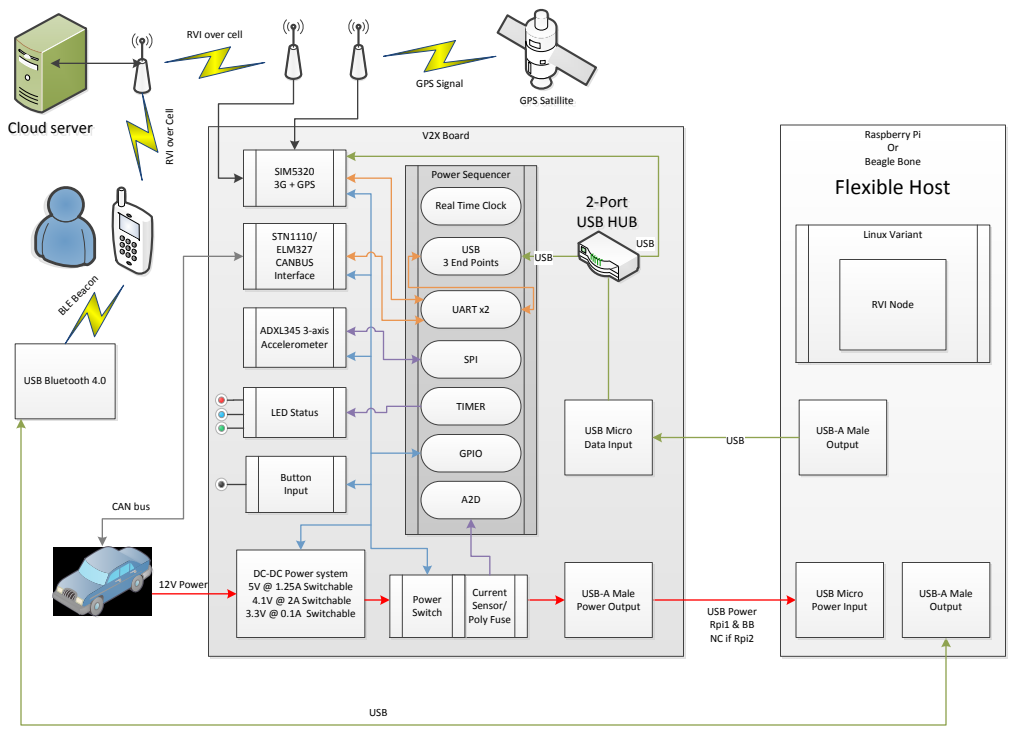
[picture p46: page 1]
V2X Board; Power Sequencer SIM5320 3G + GPS; GPS Signal; GPS Satillite; Raspberry Pi Or Beagle Bone; ADXL345 3-axis Accelerometer; USB Bluetooth 4.0; BLE Beacon; Linux Variant; RVI Node; Flexible Host; USB; 12V Power; CAN bus; USB Power Rpi1 & BB NC if Rpi2; USB Micro Power Input; USB-A Male Output; USB-A Male Power Output; USB Micro Data Input; 2-Port USB HUB; STN1110/ ELM327 CANBUS Interface; Current Sensor/ Poly Fuse; UART x2; SPI; Button Input; GPIO; Power Switch; USB 3 End Points

RVI over cell

RVI over Cell

Real Time Clock

TIMER LED Status

DC-DC Power system
5V @ 1.25A Switchable
4.1V @ 2A Switchable
3.3V @ 0.1A Switchable

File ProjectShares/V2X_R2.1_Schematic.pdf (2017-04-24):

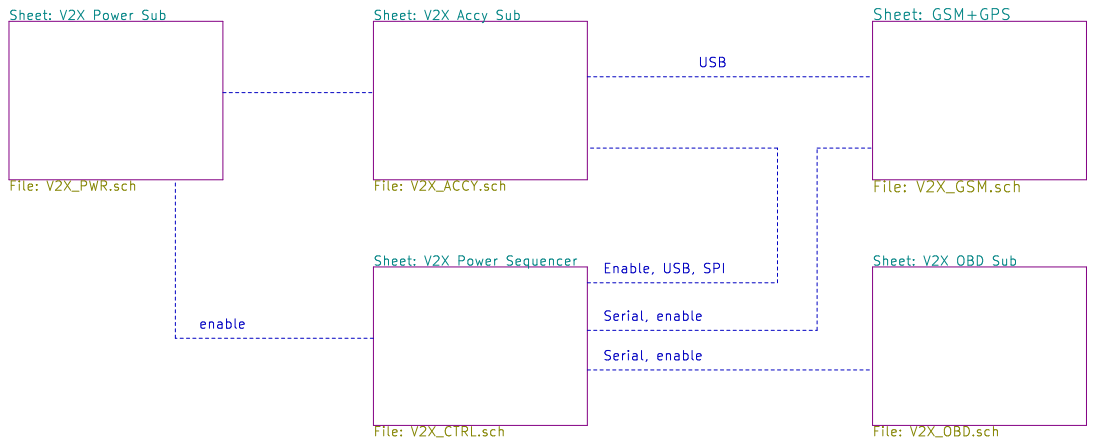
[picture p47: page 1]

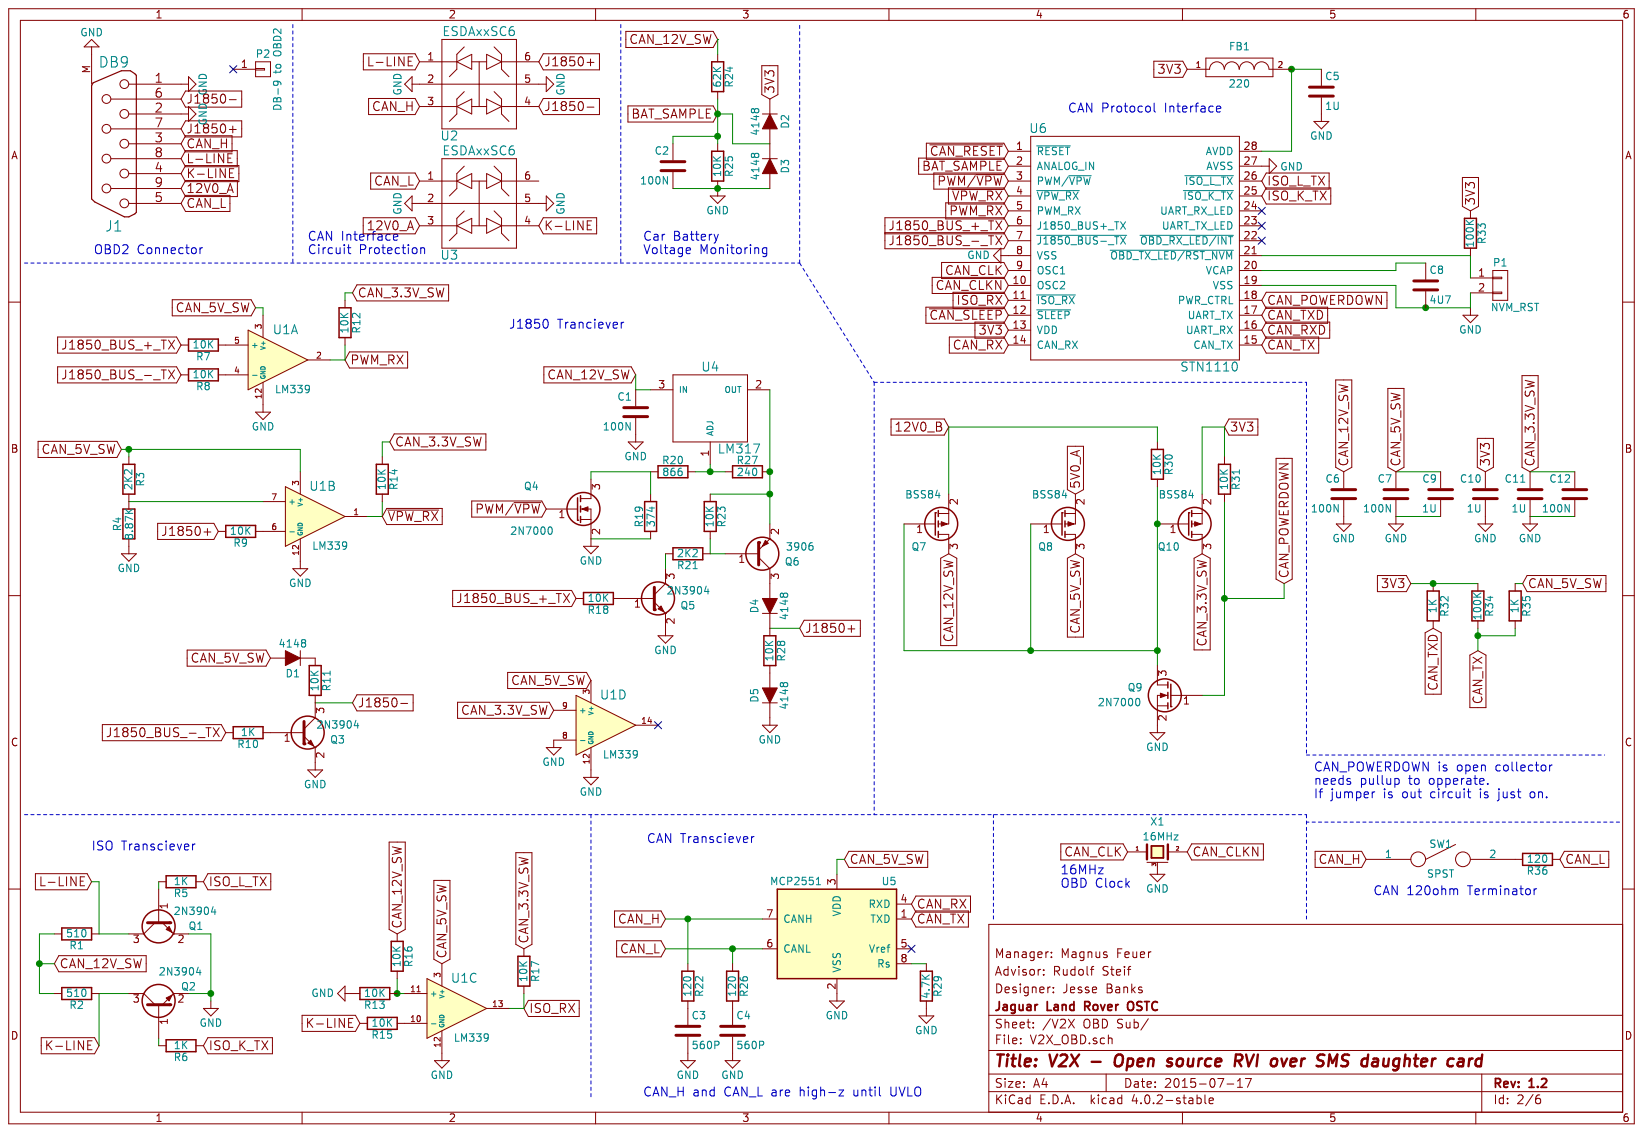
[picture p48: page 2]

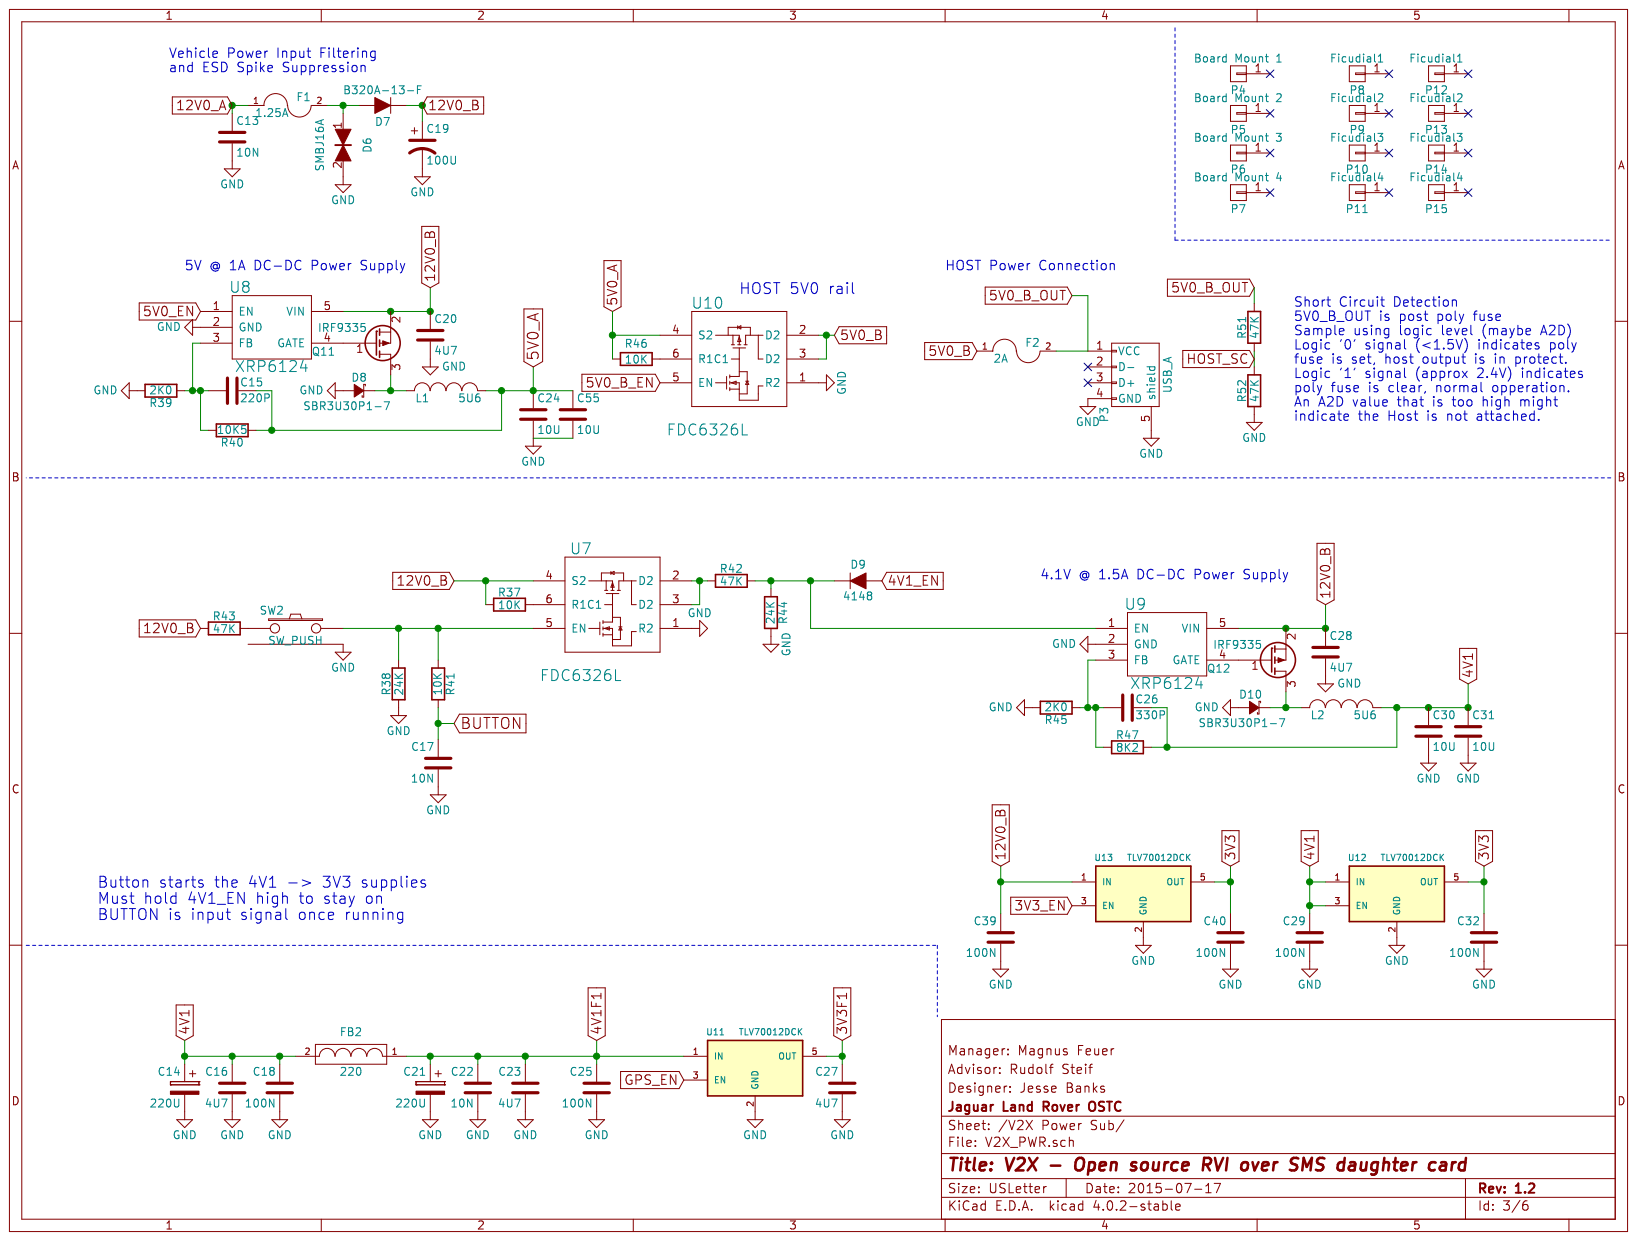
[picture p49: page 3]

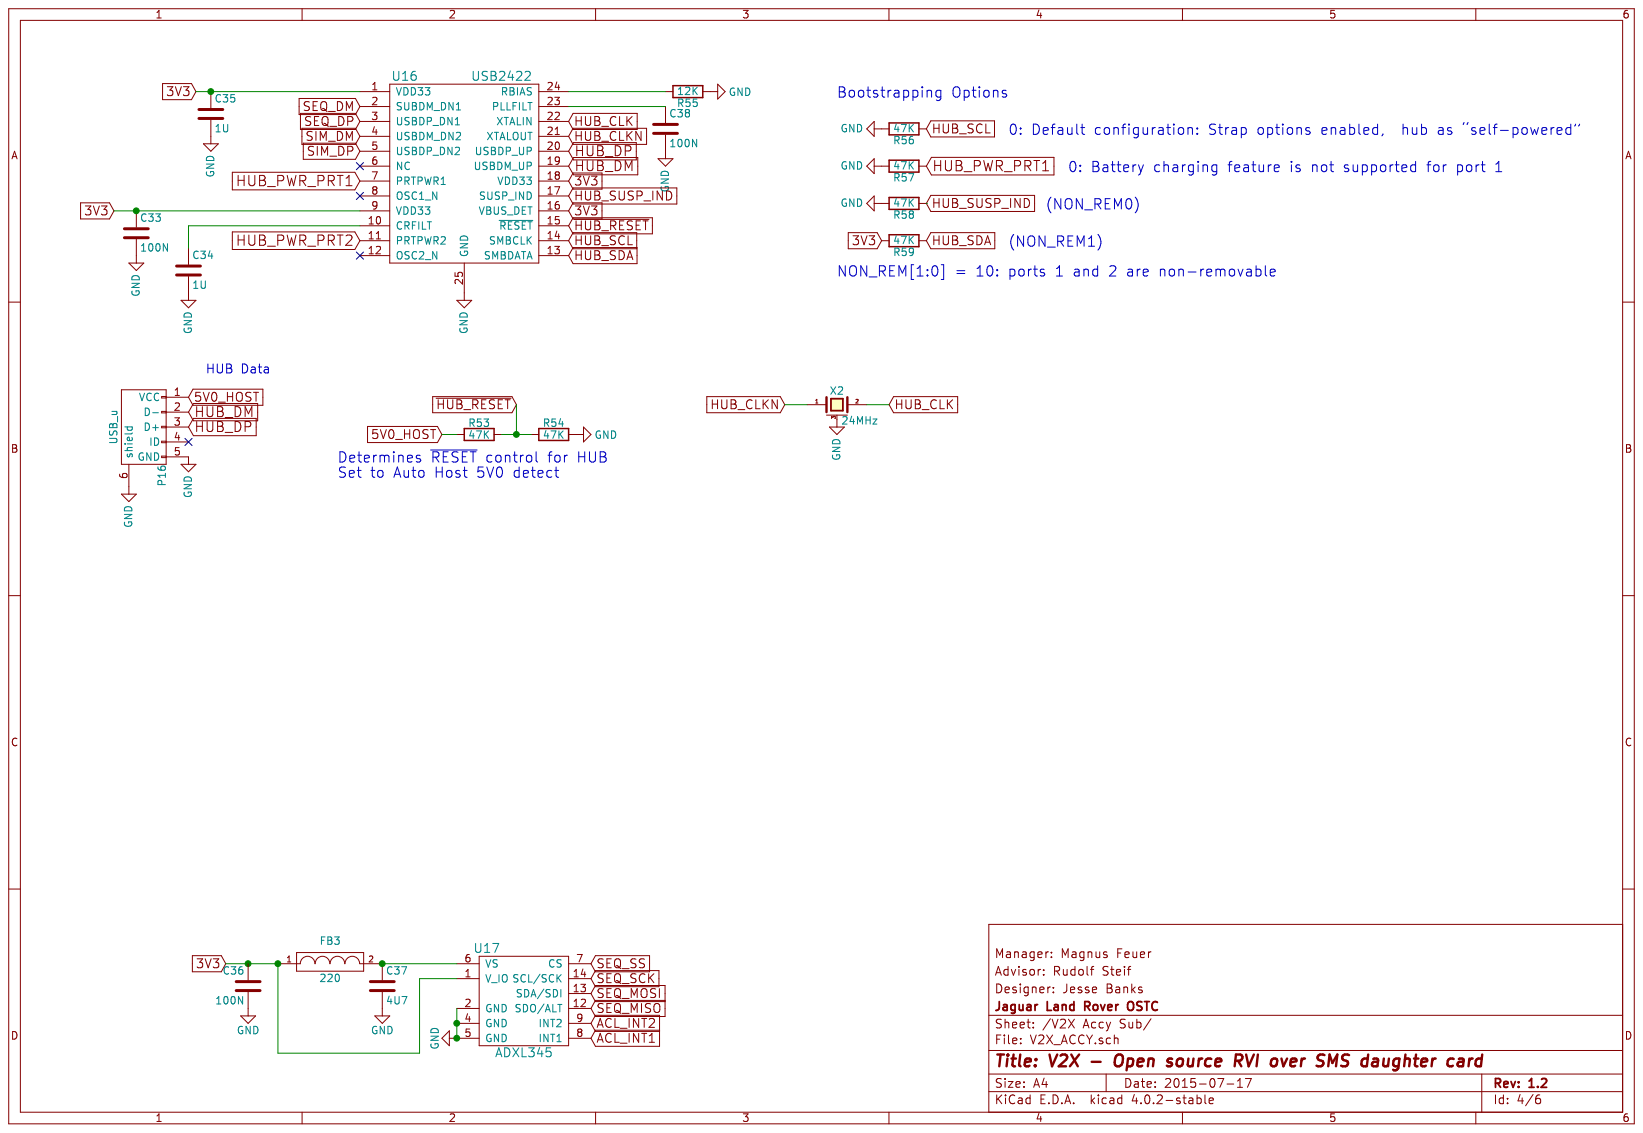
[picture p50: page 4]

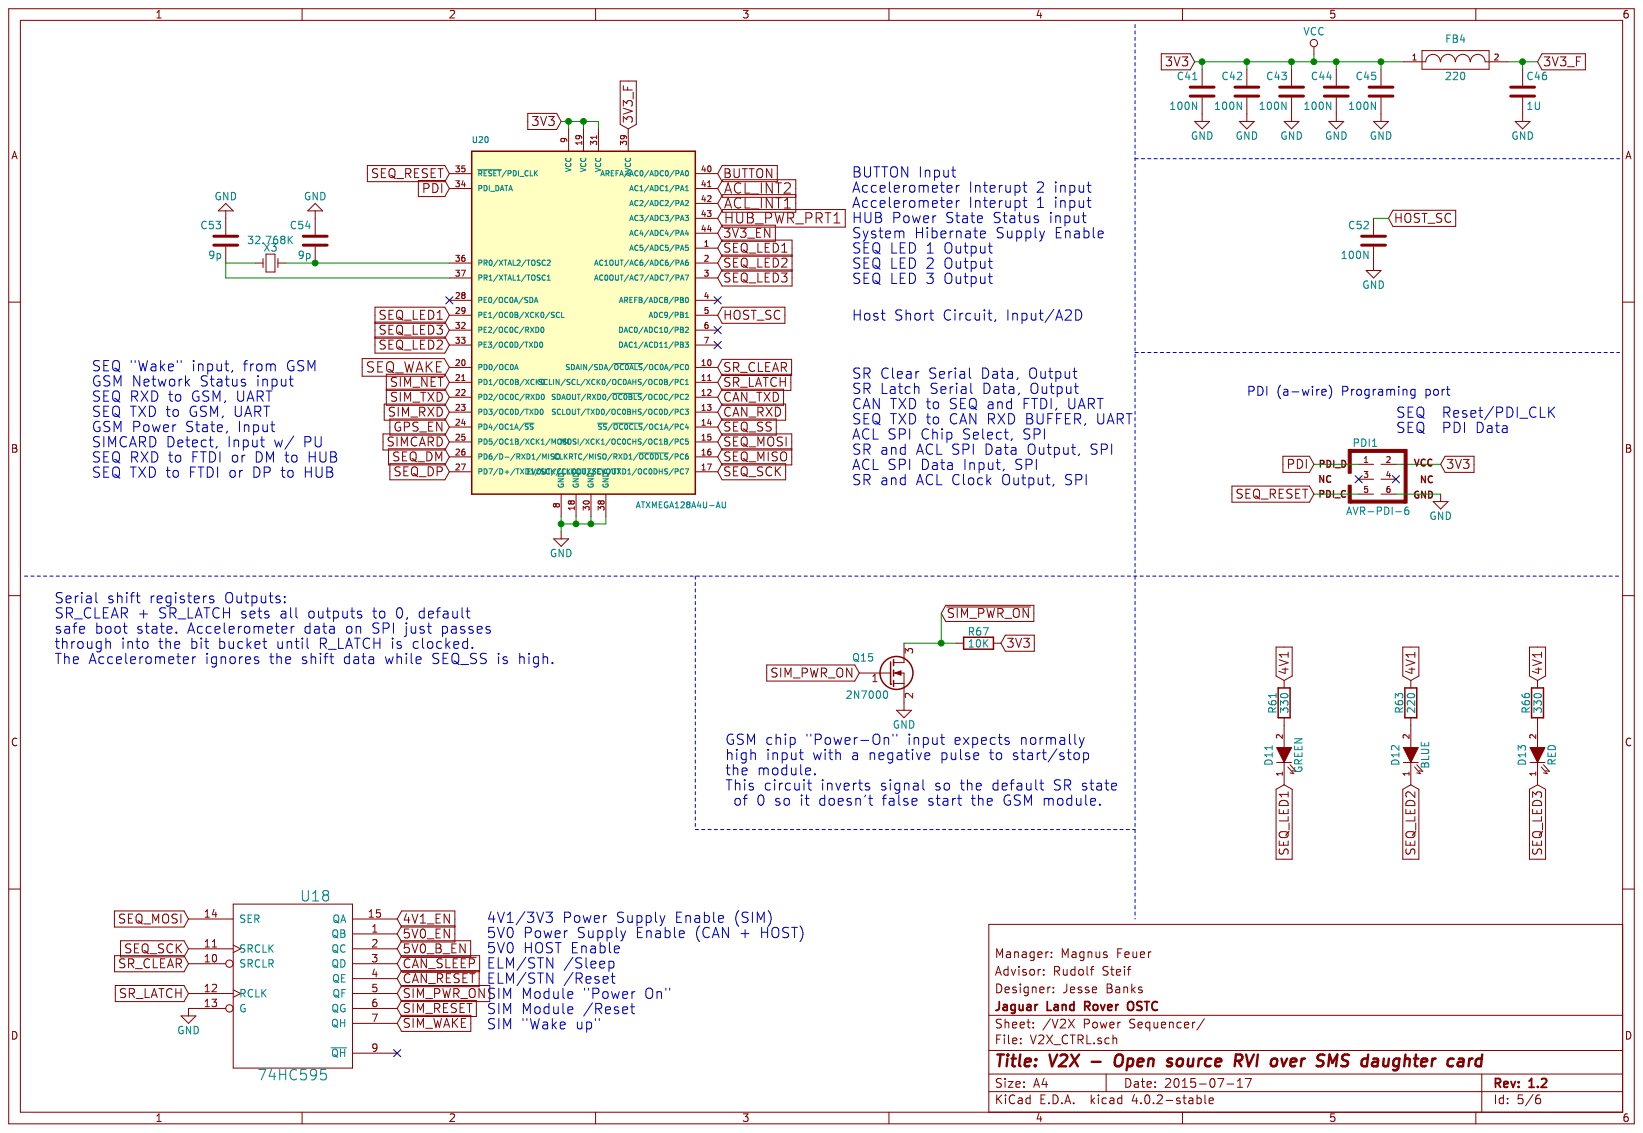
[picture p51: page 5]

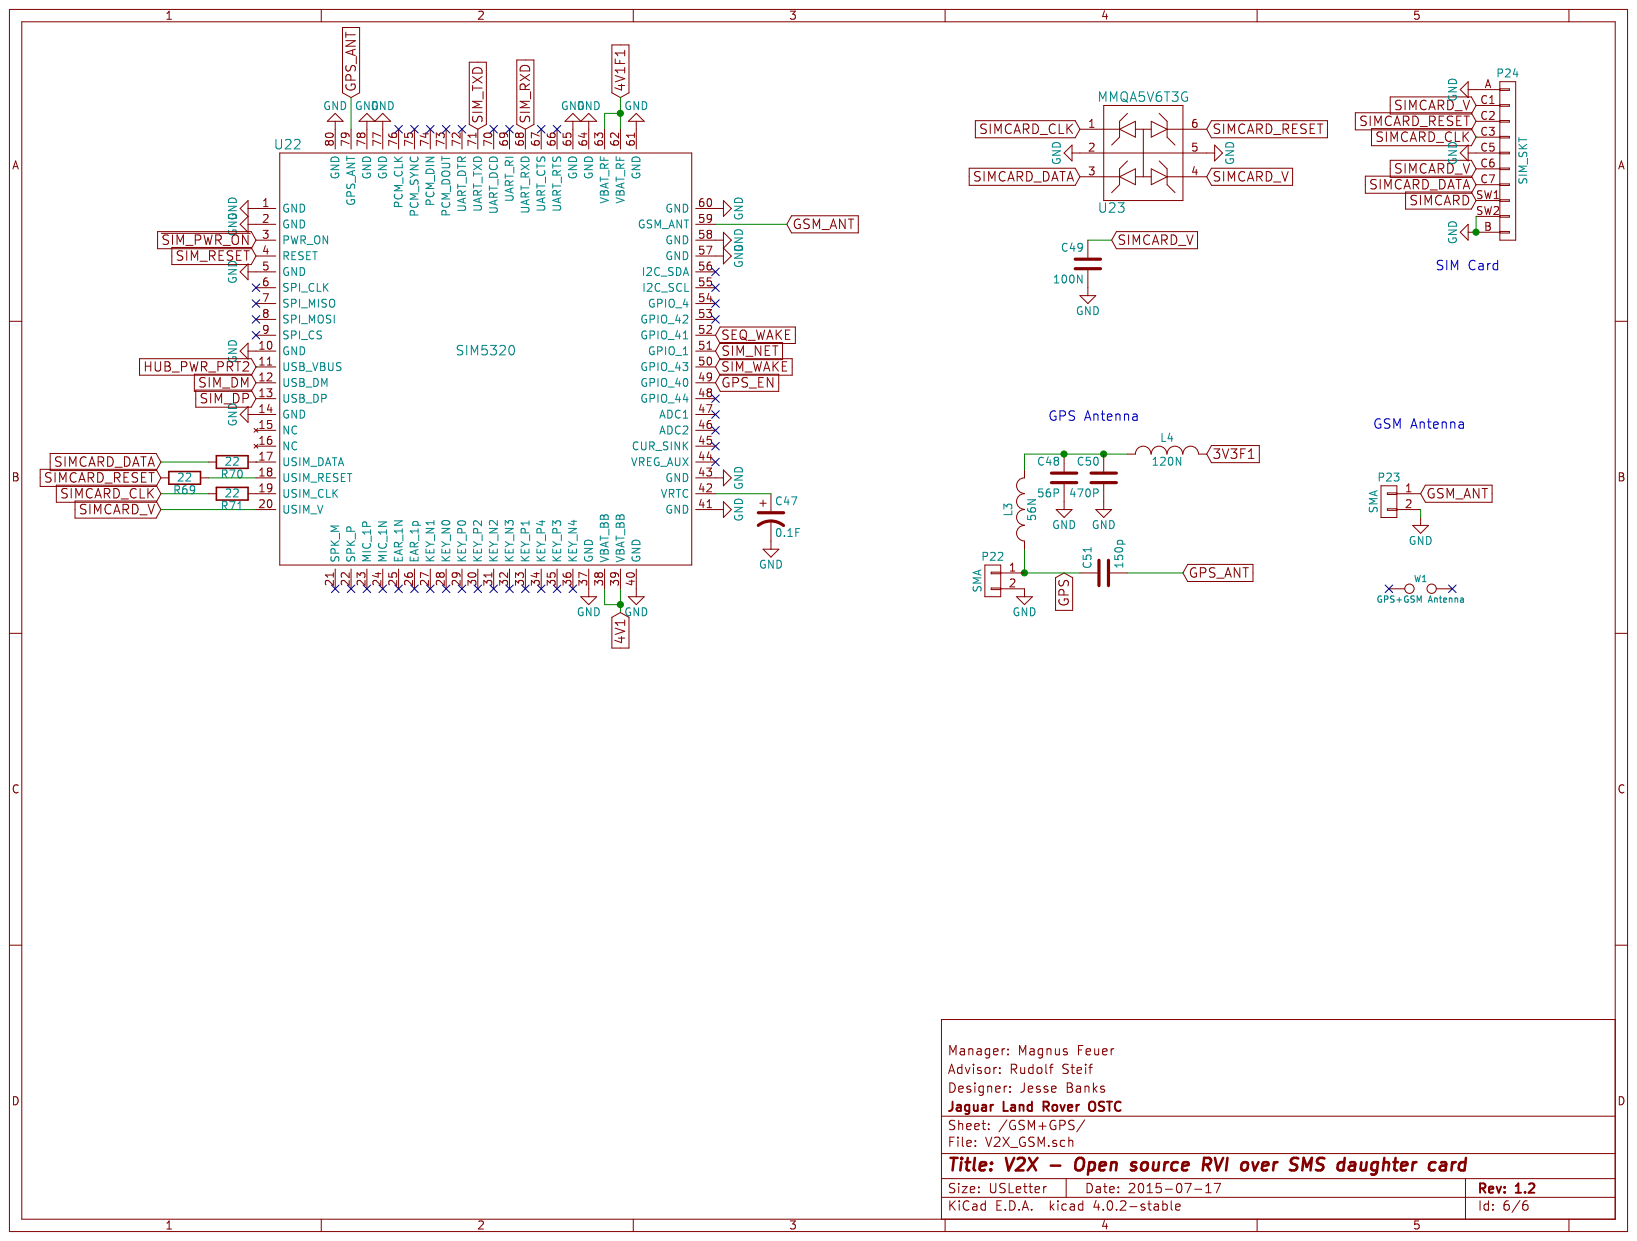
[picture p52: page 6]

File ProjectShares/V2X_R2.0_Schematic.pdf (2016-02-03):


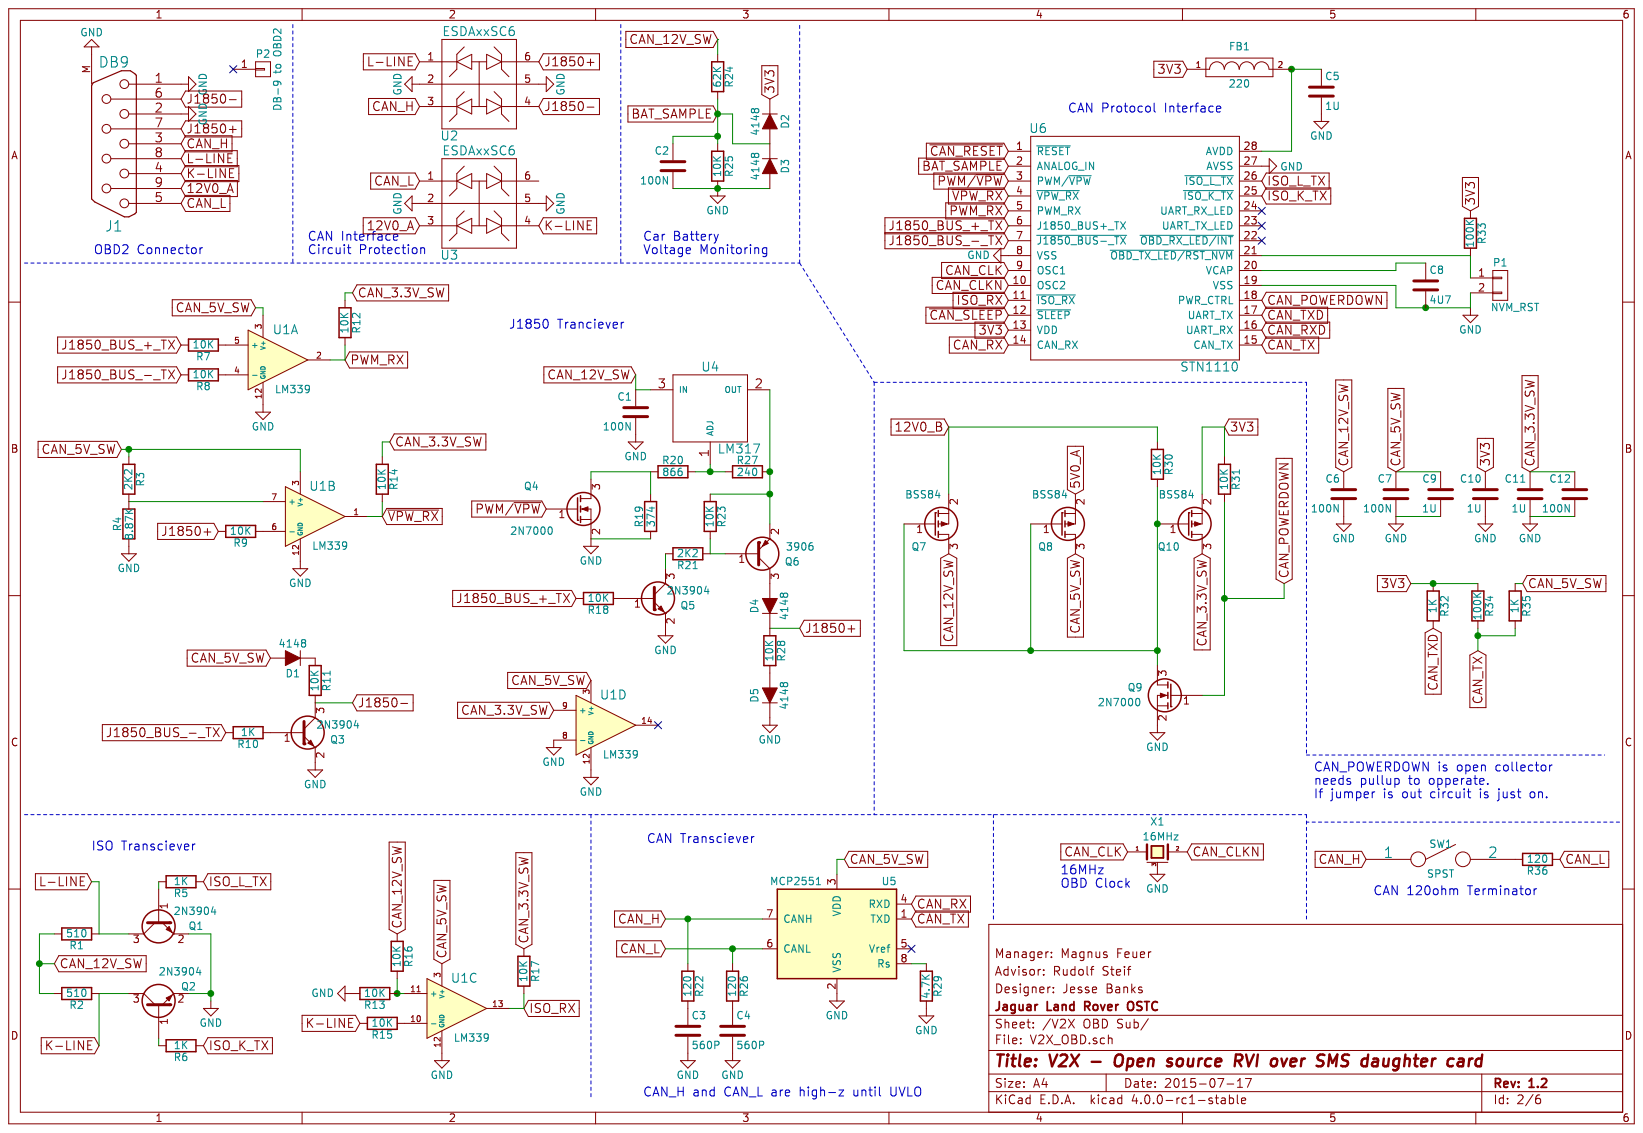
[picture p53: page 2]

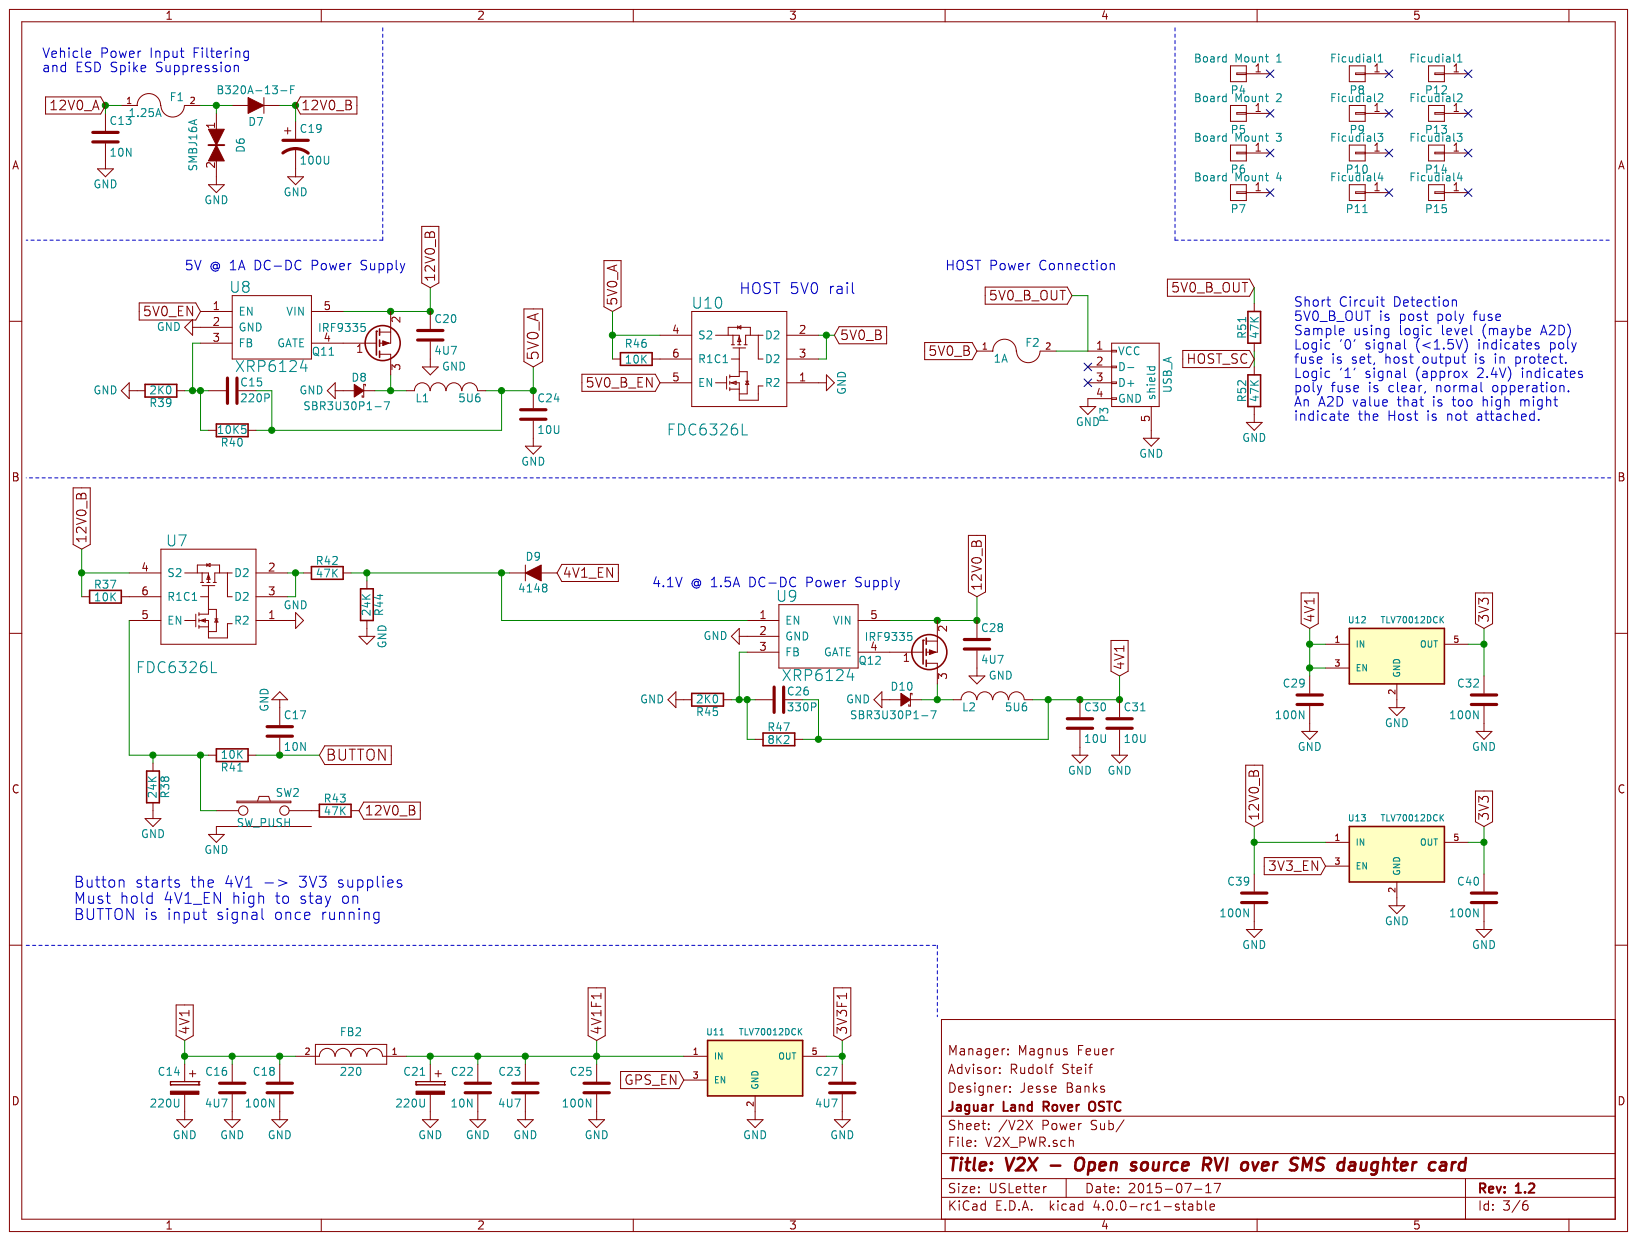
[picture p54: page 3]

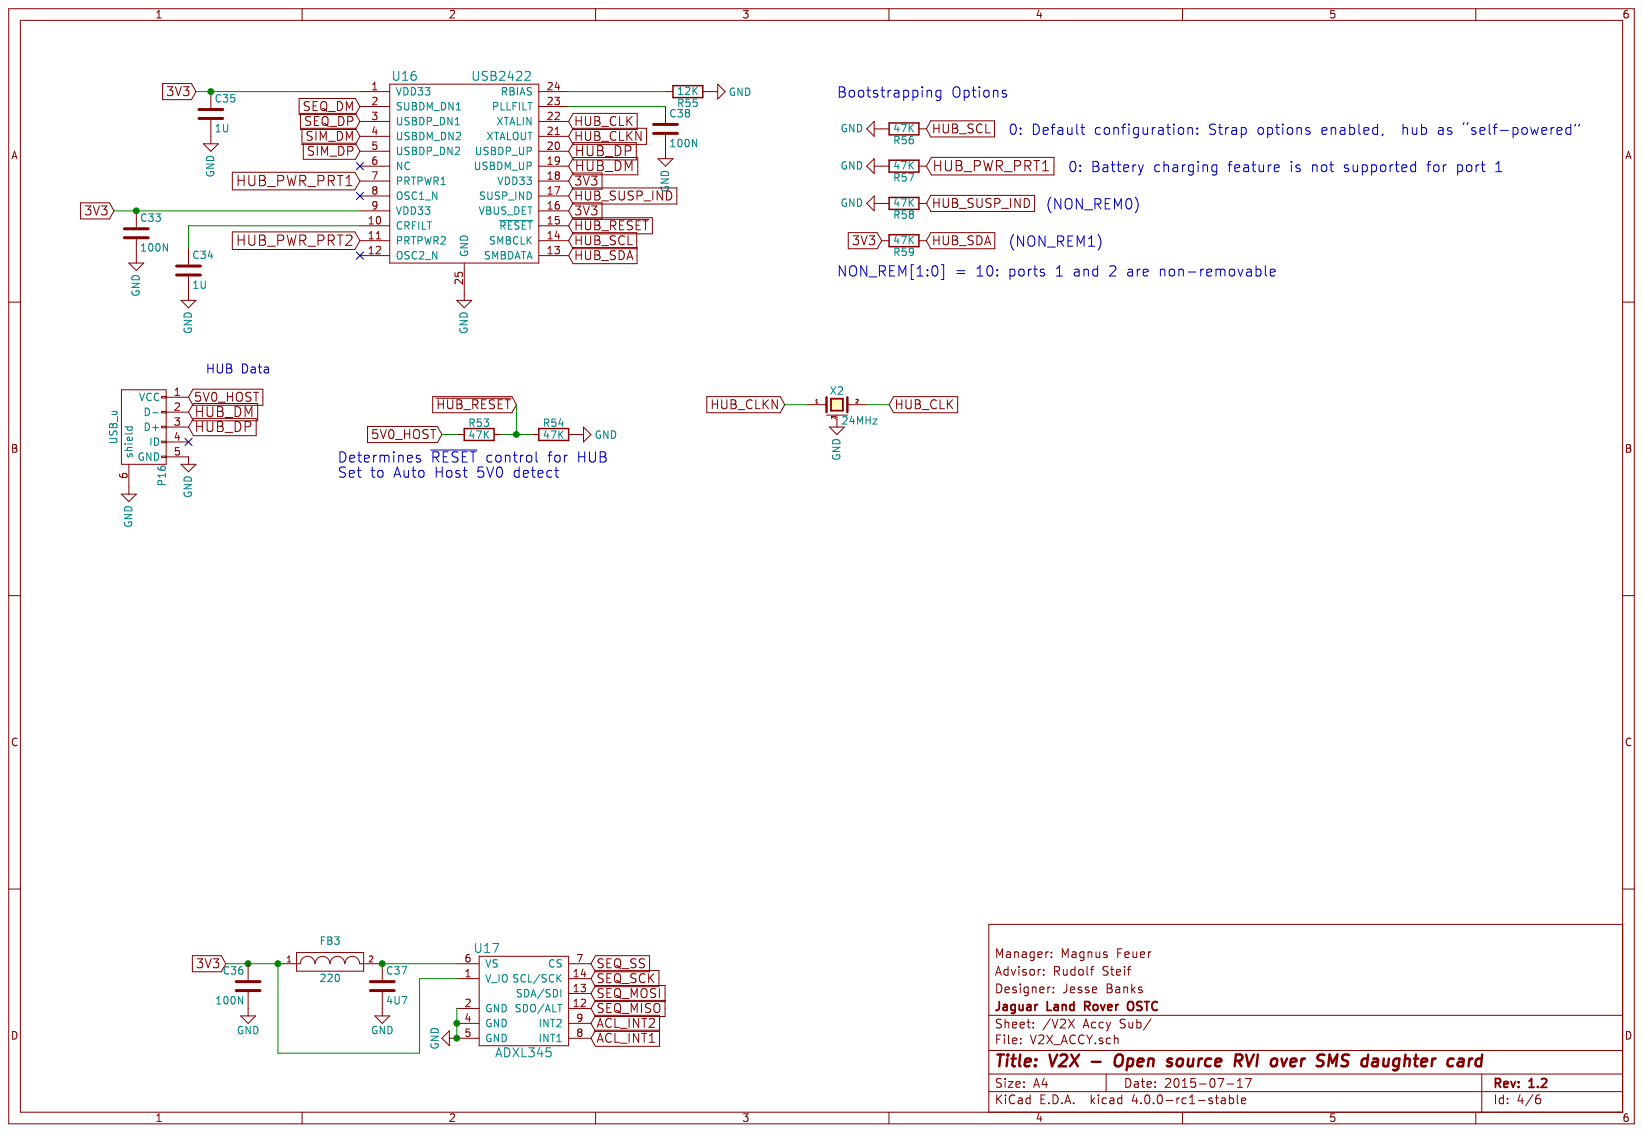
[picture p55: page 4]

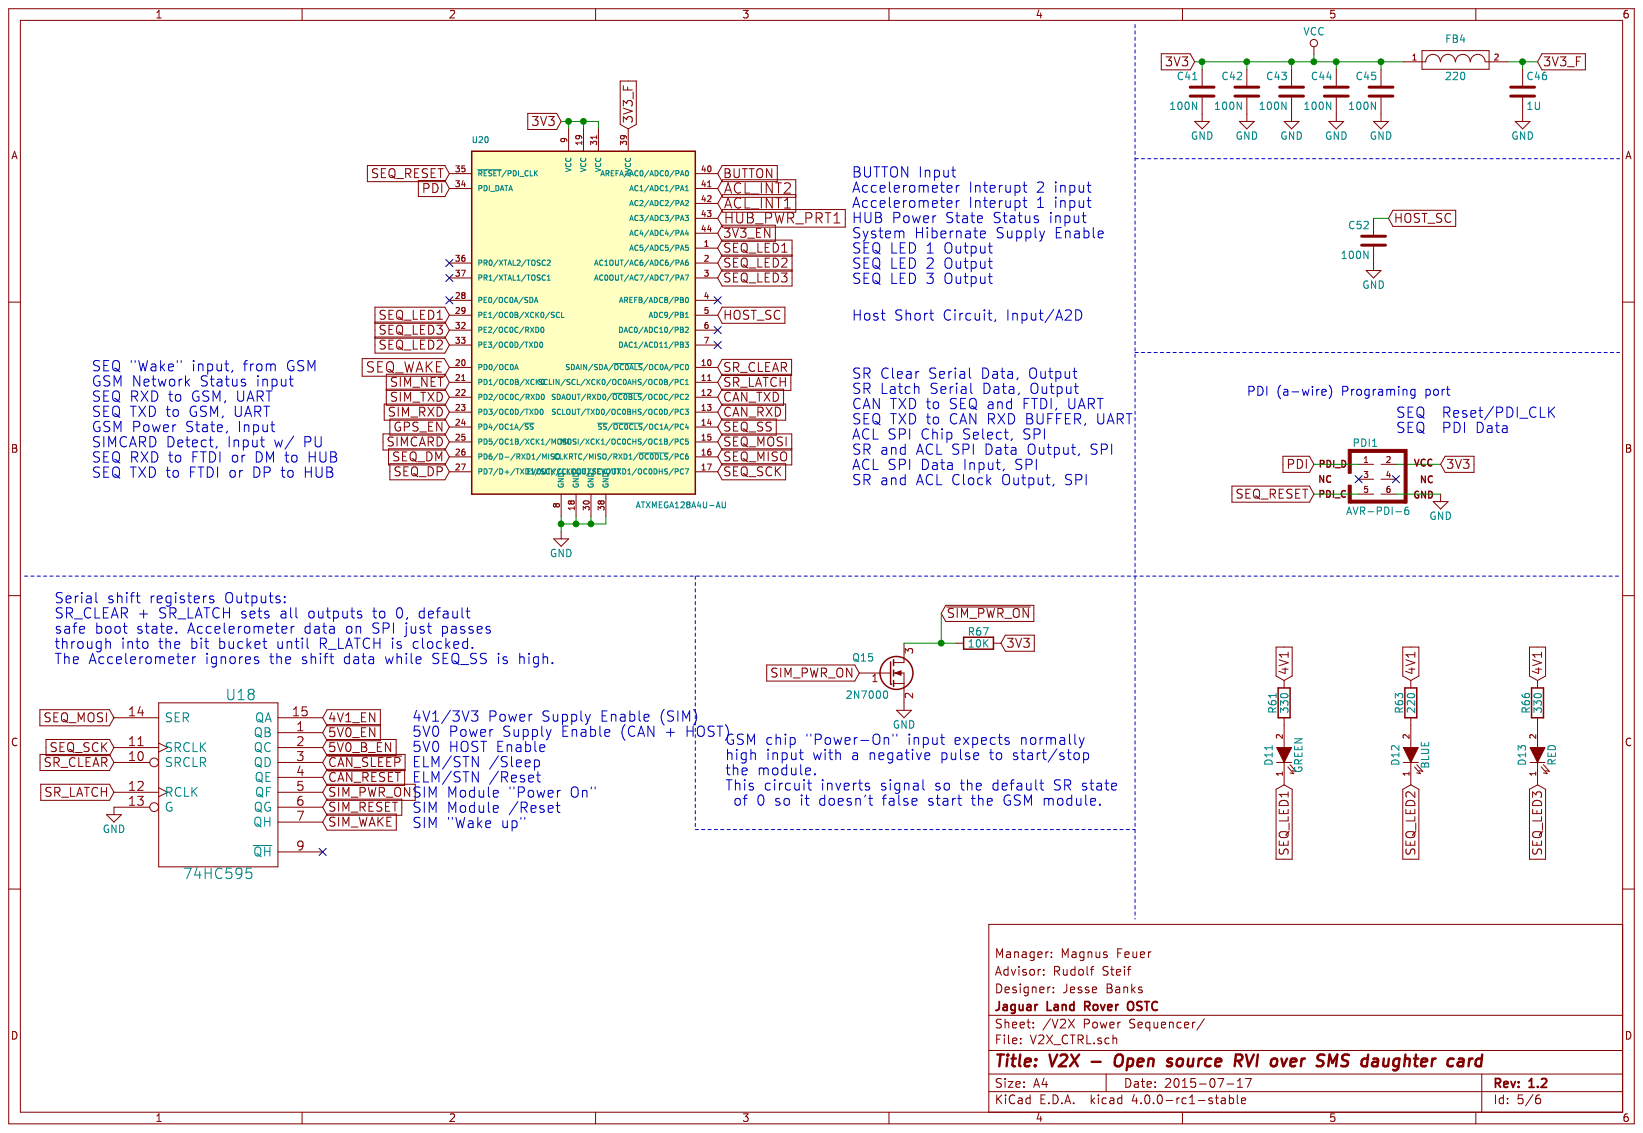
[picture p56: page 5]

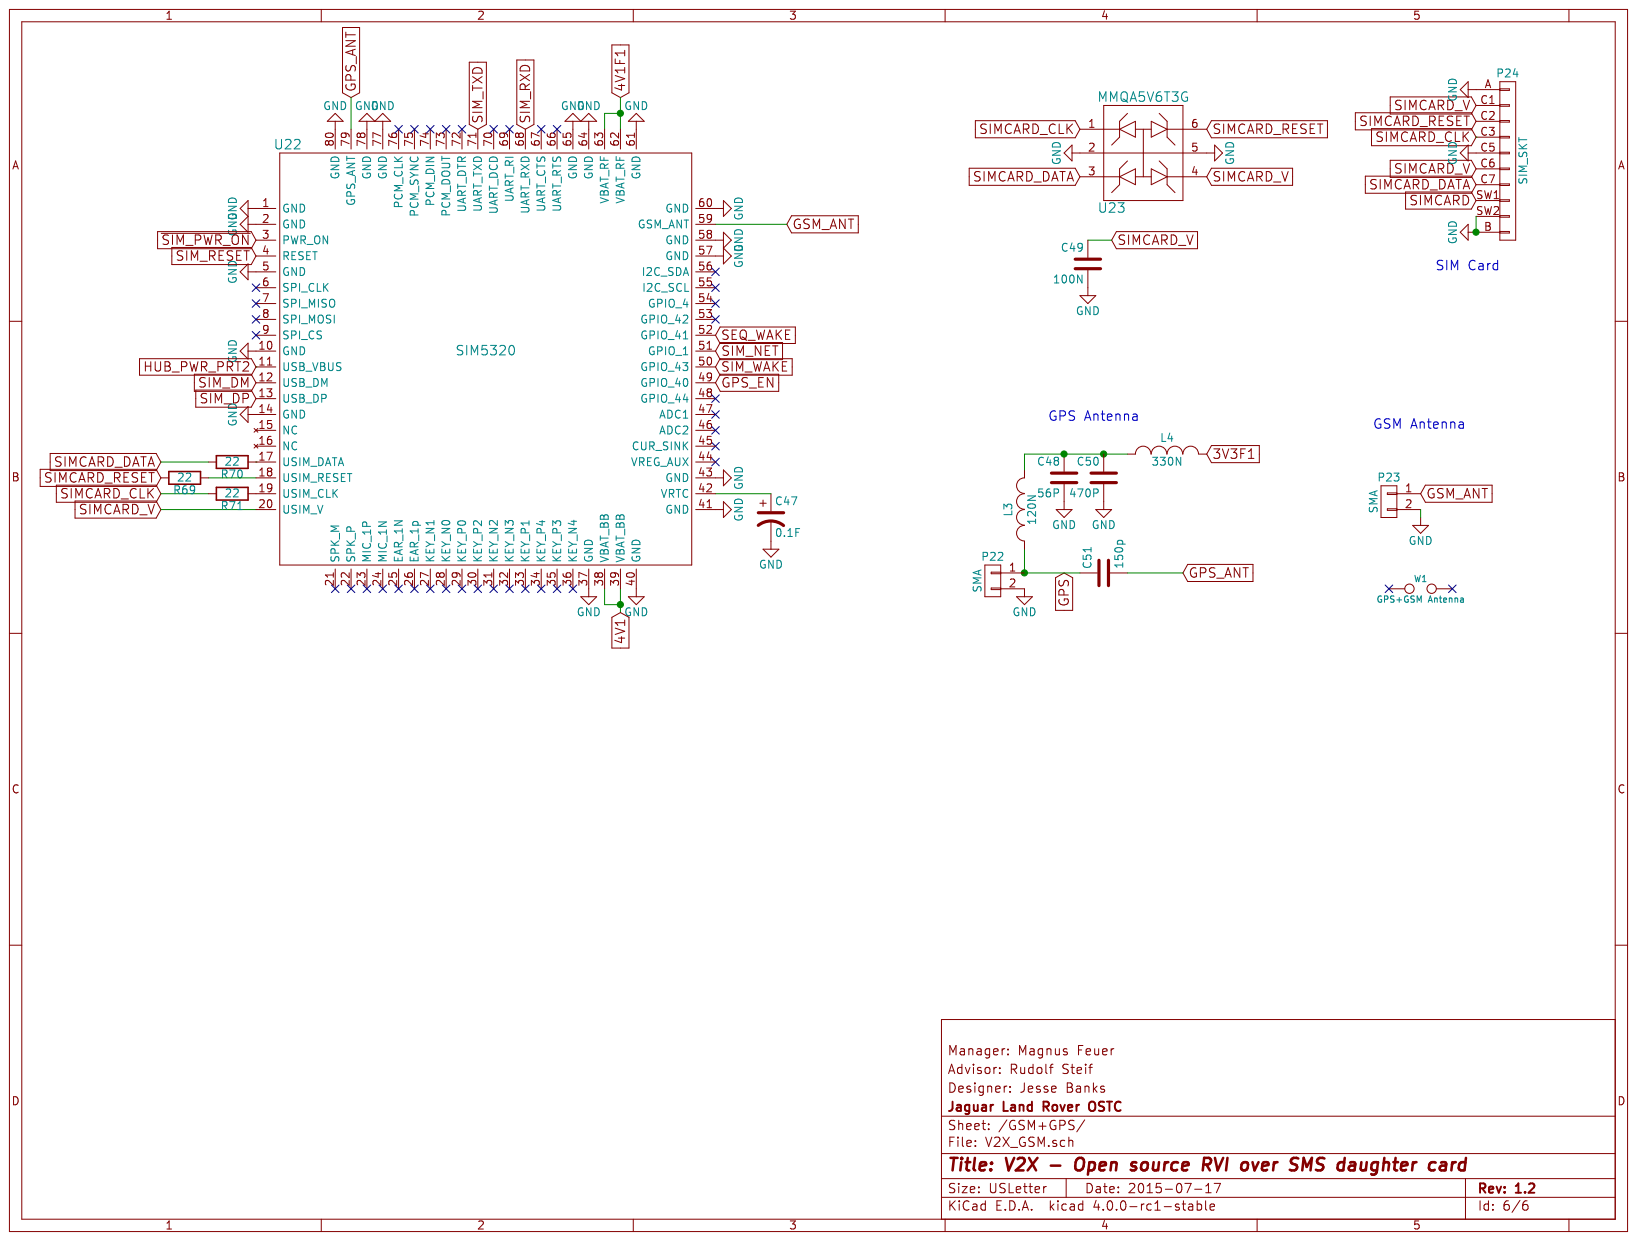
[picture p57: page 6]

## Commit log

2016-02-03 53851 Import of V2X R1.0
    Capture from other repo
    [OBD2_SMS-B_Cu.gbl, OBD2_SMS-B_Mask.gbs, OBD2_SMS-B_SilkS.gbo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]
2016-02-03 53851 Import of V2X R1.2
    Copied from legacy repo
    [OBD2_SMS-B_Cu.gbl, OBD2_SMS-B_Mask.gbs, OBD2_SMS-B_SilkS.gbo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]
2016-02-03 53851 Import of V2X R2.0
    capture from legacy repo
    [V2X-B_Cu.gbl, V2X-B_Mask.gbs, V2X-B_SilkS.gbo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]
2016-03-07 added high accuracy 32K crystal for RTC
    only schematic
    [V2X.kicad_pcb, V2X_CTRL.sch, V2X_GSM.sch]
2016-03-07 Added 32K RTC clock to layout
    little cleanup, parts added. RTC 55701
    [V2X-B.Cu.gbl, V2X-B.Mask.gbs, V2X-B.SilkS.gbo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]
2016-05-23 SIM module app research
    [qdl.cfg]
2016-10-18 Changes for documentation
    [V2X.kicad_pcb, V2X.sch, V2X_ACCY.sch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]
2016-10-18 Documentation import
    [V2X functions Definition.xlsx]
2017-04-02 Updated Xtal footprint
    16 & 24mhz crystal footprints were too small
    [V2X.sch, V2X_ACCY.sch, V2X_CTRL.sch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]
2017-04-02 Part numer updates
    for error or out of stock
    [V2X_ACCY.sch, V2X_CTRL.sch, V2X_GSM.sch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]
2017-04-24 Rev2.1 produced
    Built R2.0, included findings, minor tweaks to placment and BOM.
    [GENIVI_Logo_Full.dxf, MouserOrderR2.1.xls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]
